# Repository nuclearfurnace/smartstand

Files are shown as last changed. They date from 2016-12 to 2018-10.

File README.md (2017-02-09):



# What is the SmartStand?

The SmartStand is a headphone stand that features not only a built-in, high-quality USB DAC and headphone amplifier, but the ability to detect when your headphones are in use (off the stand) and automatically switch between headphone output and line out, all while presenting as a normal USB audio device to your computer.

# What are the specifications?  How does it sound?

I'm not sure yet!  I haven't reached a rev A for the final design.  Here's the rough breakdown of what the design has:

- XMOS processor for the USB controller ([datasheet](https://www.xmos.com/download/private/XUF208-256-TQ64-Datasheet%281.10%29.pdf), can support UAC2 up to 384kHz at 2 channels)
- TI [PCM5102A](http://www.ti.com/lit/ds/symlink/pcm5102a.pdf) for the DAC
- low-noise power supplies
    - 12V DC wall wart which feeds
        - a TI [TPS563200](http://www.ti.com/lit/ds/symlink/tps563200.pdf) synchronous step-down converter which feeds
            - a TI [TPS7A8300](http://www.ti.com/lit/ds/symlink/tps7a8300.pdf) which provides the 1V0 core supply
        - a TI [TPS563200](http://www.ti.com/lit/ds/symlink/tps563200.pdf) synchronous step-down converter which feeds
            - a TI [TPS7A8300](http://www.ti.com/lit/ds/symlink/tps7a8300.pdf) which provides the digital 3V3 supply
            - a TI [TPS7A8300](http://www.ti.com/lit/ds/symlink/tps7a8300.pdf) which provides the analog 3V3 supply
        - a TI [TPS7A4701](http://www.ti.com/lit/ds/symlink/tps7a47.pdf) which provides the positive 11V0 amplifier rail
        - a TI [TPS7A3301](http://www.ti.com/lit/ds/symlink/tps7a33.pdf) which provides the negative 11V0 amplifier rail
- amplifier section that mirrors the [Objective2](http://nwavguy.blogspot.com/2011/07/o2-headphone-amp.html) headphone amplifier
    - an [NJM2068](http://www.njr.com/semicon/PDF/NJM2068_E.pdf)-based gain stage, with internal switches for dual gain settings
    - an Alps [RK14K](http://www.alps.com/prod/info/E/HTML/Potentiometer/RotaryPotentiometers/RK14K12/RK14K1240A4S.html) volume control pot after the gain stage, big and chunky (1B taper)
    - paralleled [NJM4556A](http://www.njr.com/semicon/PDF/NJM4556A_E.pdf)s for the output stage for lots o' power
- relay-based switching between headphone outputs and line outs, as well as relay-based protection on the headphone outputs to avoid pops and thumps
- Neutrik [NRJ6HH](http://www.neutrik.com/en/audio/plugs-and-jacks/slim-jacks/nrj6hh) 1/4" headphone jack
- Switchcraft [PJRAN2X1U01AUX](http://www.switchcraft.com/Drawings/pjran2x1u__x_series_cd.pdf) RCA outputs
- TE USB type B connector [292304-1](http://www.te.com/usa-en/product-292304-1.html)
- 0.1% precision resistors, and NP0/C0G capacitors in the audio path

# What's in this repository?

This repository will hold all the Eagle CAD design files for the internals, including:

- original, sloppy evaluation boards for the XMOS processor and amplifier section
- the integrated USB DAC/amplifier board (single board that will be used in the unit)
- proximity sensor board (will be located in the stand arm where the headphones rest)
- any schematic- or board-related design files i.e. DRC rules, 3D IDF data, etc

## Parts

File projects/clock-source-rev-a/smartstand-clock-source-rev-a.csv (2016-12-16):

Part | Value | Device | Package | Description | PN
C1 | 100nF | C-EUC0402 | C0402 | CAPACITOR, European symbol | GRM155R71C104KA88D
C2 | 1uF | C-EUC0603 | C0603 | CAPACITOR, European symbol | GRM188R61C105KA93D
J1 | RECE-20279-001E-01 | RECE-20279-001E-01 | IPEX-MHF |  | RECE-20279-001E-01
JP1 |  | PINHD-1X5 | 1X05 | PIN HEADER | 90120-0125
X1 | KC2520K | KC2520K | KC2520C | Clock Oscillators, CMOS, 1.8V/2.5V/3.3V Compatible, 2.5×2.0mm | KC3225K24.5760C1GE00

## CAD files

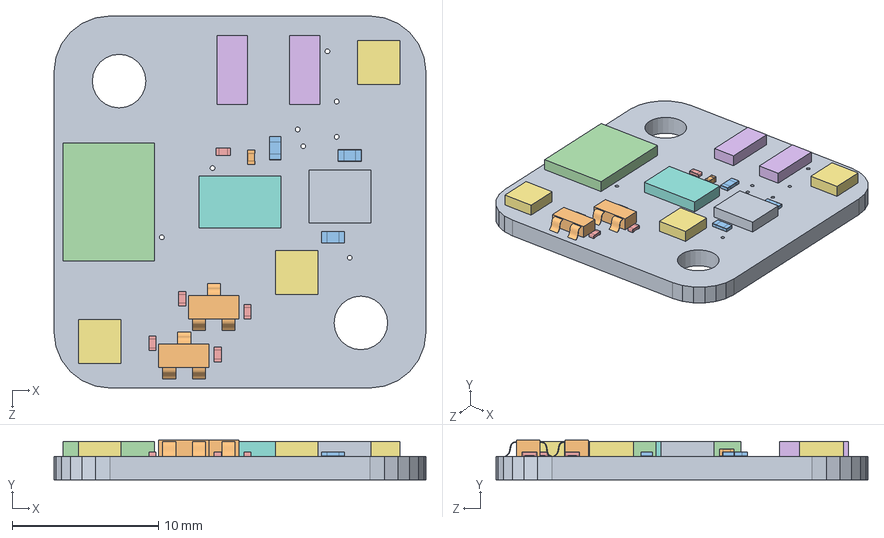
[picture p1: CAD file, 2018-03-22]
enclosure/smartstand-headphone-detection-rev-c.SLDASM
25.4 x 2.70 x 25.4 mm
smartstandheadphonedetectionrevc
C0402
C0603 x 3
T1MSINGLE5POS_T1M5POS
R0402 x 5
TESTPOINT1_5WITHGND_TESTPOINTWITHGND x 2
FIDUCIAL_1MM_FIDUCIAL1MM x 3
VL6180X_VL6180XV0NR
RPDSOG5DBV_LP5907MFX2_8
sot23_4210037 x 2

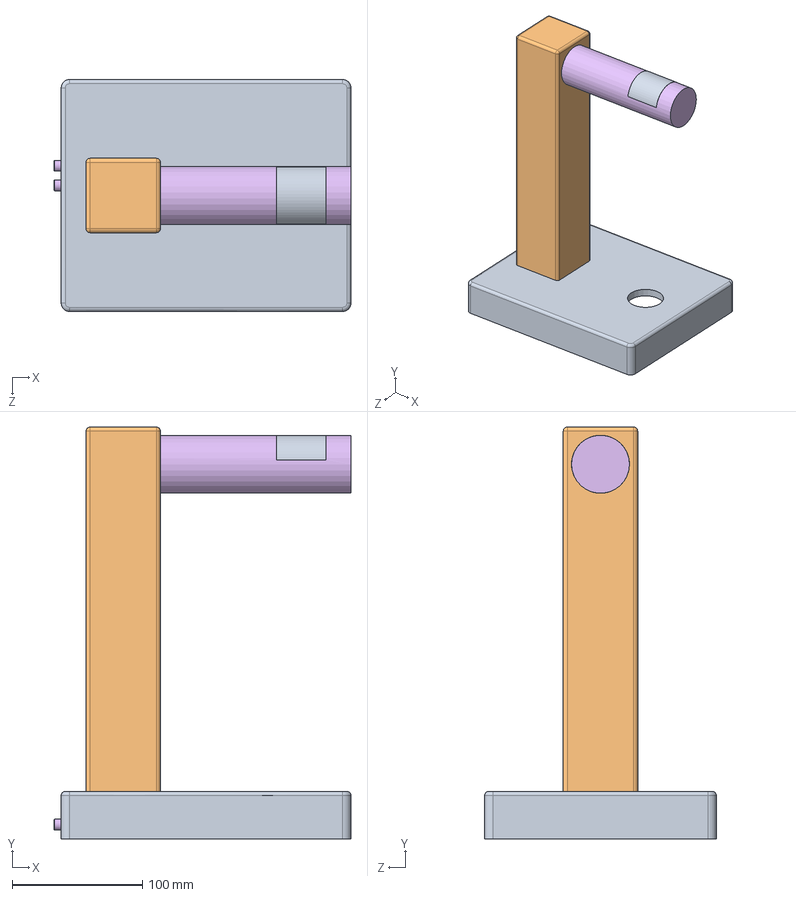
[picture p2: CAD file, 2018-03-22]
enclosure/smartstand-enclosure.SLDASM
227.7 x 315.9 x 177.8 mm
smartstand-enclosure-base
smartstand-enclosure-upright
90016A029_BRASS TAPPING INSERTS FOR HARDWOOD x 4
92240A541_18-8 STAINLESS STEEL HEX HEAD CAP SCREW x 4
91525A118_TYPE 316 STAINLESS STEEL FLAT WASHER x 4
smartstand-enclosure-arm
smartstandheadphonedetectionrevc
C0402 x 75
C0603 x 17
T1MSINGLE5POS_T1M5POS x 2
R0402 x 50
TESTPOINT1_5WITHGND_TESTPOINTWITHGND x 12
FIDUCIAL_1MM_FIDUCIAL1MM x 11
VL6180X_VL6180XV0NR
RPDSOG5DBV_LP5907MFX2_8
sot23_4210037 x 2
smartstand-enclosure-sensor-cover
smartstandusbdacamplifierrevb
CHEMICON_F55_CHEMICON_F55 x 6
C0805 x 22
C1206 x 4
KEMET5MM6_07_2_KEMET5MM6_07_2 x 2
SOD128_5A
SMA_13_6V
DIALIGHT-0603 x 6
2920L_0_6A
PJ002A_PJ002A
NRJ6HH_NRJ6HH
PJRAN2X1U01AUX
N2520-5002
1X07_JP3_1X07
TDKVLP8040_TDKVLP8040 x 2
R1206 x 4
TQ2_TQ212V x 2
TQFP64EXPOSEDPAD_XUF208256TQ64
RPUSONN10_TPD4E02B04DQA
RPDSOG6DBV_TS5A3159DBV x 4
SPVQFNN20_TPS7A3301RGW x 5
RPDSOG20_PCM5102A
SOT457_SZNUD3124
DMP8_NJM4556AM x 3
RPDSOG8DCU_SN74LVC3G34DCU
RPDSOG3_TPD2E007DCK x 2
KC2520C_24_576MHZ x 3
93090A250_PRESS-FIT FEMALE ROUND STANDOFFS x 6
92949A144_18-8 SS BUTTON-HEAD SOCKET CAP SCREW x 6

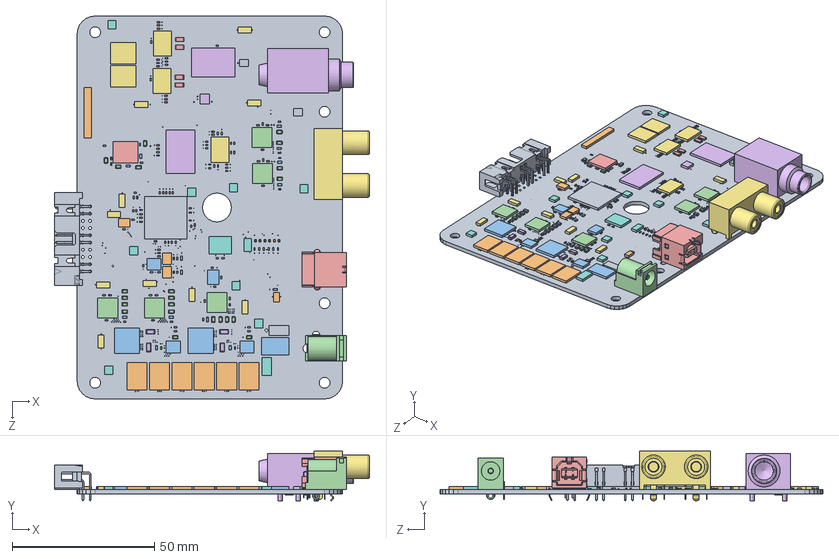
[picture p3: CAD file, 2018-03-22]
enclosure/smartstand-main-board.SLDASM
110.8 x 17.5 x 134.6 mm
smartstandusbdacamplifierrevb
CHEMICON_F55_CHEMICON_F55 x 6
C0603 x 14
C0805 x 22
C0402 x 74
C1206 x 4
KEMET5MM6_07_2_KEMET5MM6_07_2 x 2
SOD128_5A
SMA_13_6V
DIALIGHT-0603 x 6
2920L_0_6A
PJ002A_PJ002A
NRJ6HH_NRJ6HH
PJRAN2X1U01AUX
T1MSINGLE5POS_T1M5POS
N2520-5002
1X07_JP3_1X07
TDKVLP8040_TDKVLP8040 x 2
R0402 x 45
R1206 x 4
TQ2_TQ212V x 2
TESTPOINT1_5WITHGND_TESTPOINTWITHGND x 10
FIDUCIAL_1MM_FIDUCIAL1MM x 8
TQFP64EXPOSEDPAD_XUF208256TQ64
RPUSONN10_TPD4E02B04DQA
RPDSOG6DBV_TS5A3159DBV x 4
SPVQFNN20_TPS7A3301RGW x 5
RPDSOG20_PCM5102A
SOT457_SZNUD3124
DMP8_NJM4556AM x 3
RPDSOG8DCU_SN74LVC3G34DCU
RPDSOG3_TPD2E007DCK x 2
KC2520C_24_576MHZ x 3

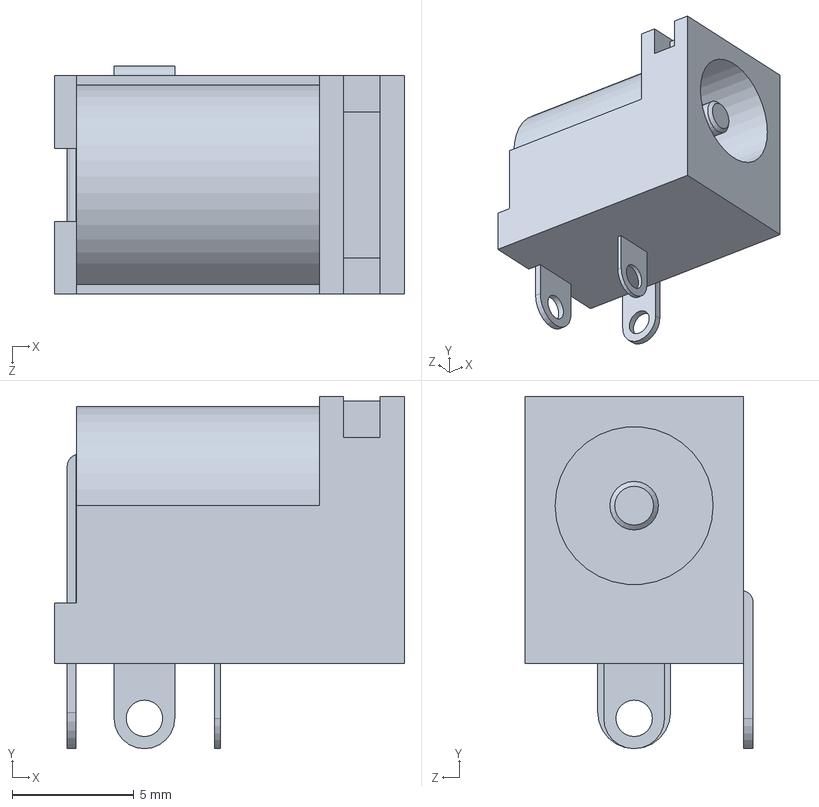
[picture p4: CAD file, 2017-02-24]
enclosure/component-library/pj-002a.SLDPRT
14.4 x 14.5 x 9.40 mm

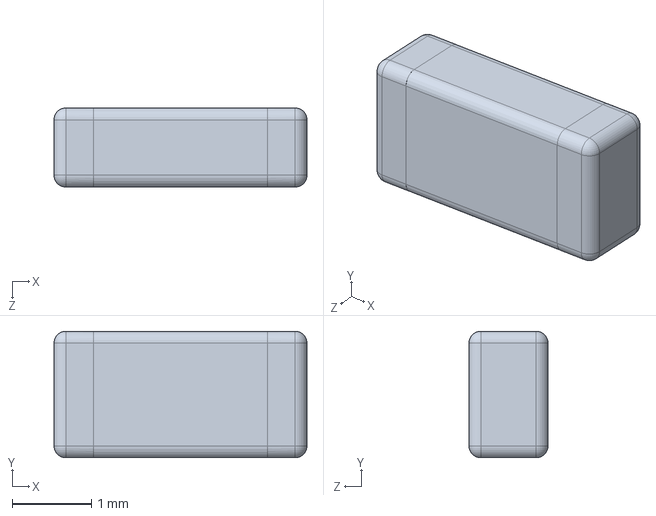
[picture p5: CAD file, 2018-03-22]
enclosure/C1206.SLDPRT
3.20 x 1.60 x 1 mm

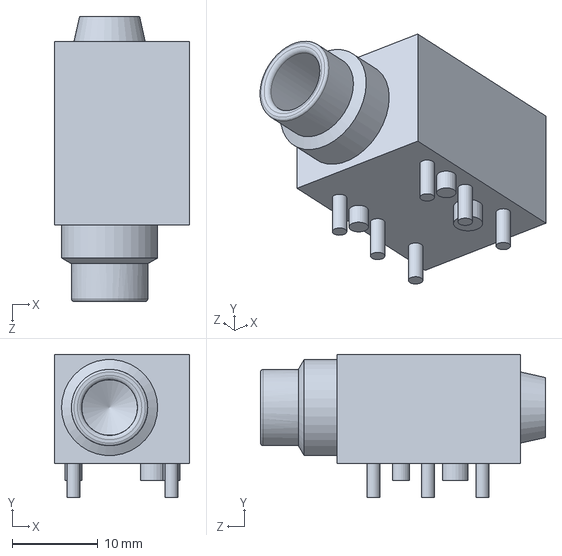
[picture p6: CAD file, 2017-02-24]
enclosure/component-library/NRJ6HH.SLDPRT
15.8 x 16.7 x 33.2 mm

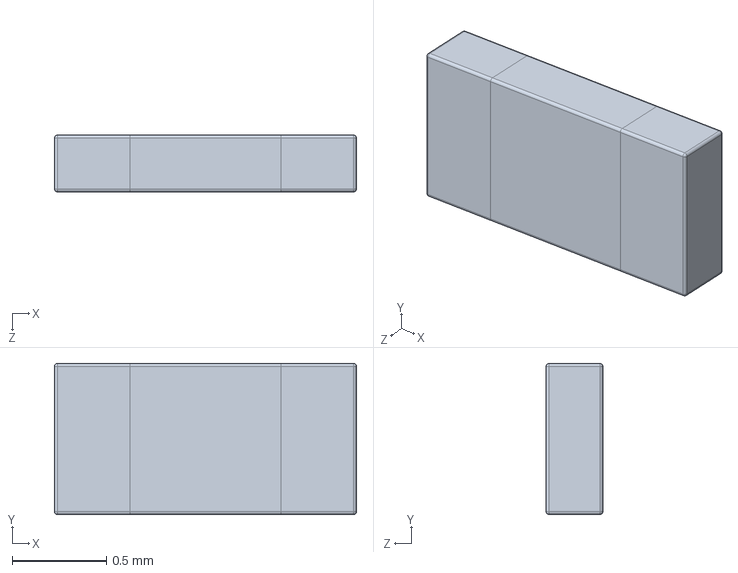
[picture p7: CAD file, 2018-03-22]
enclosure/C0603.SLDPRT
1.60 x 0.8 x 0.3 mm

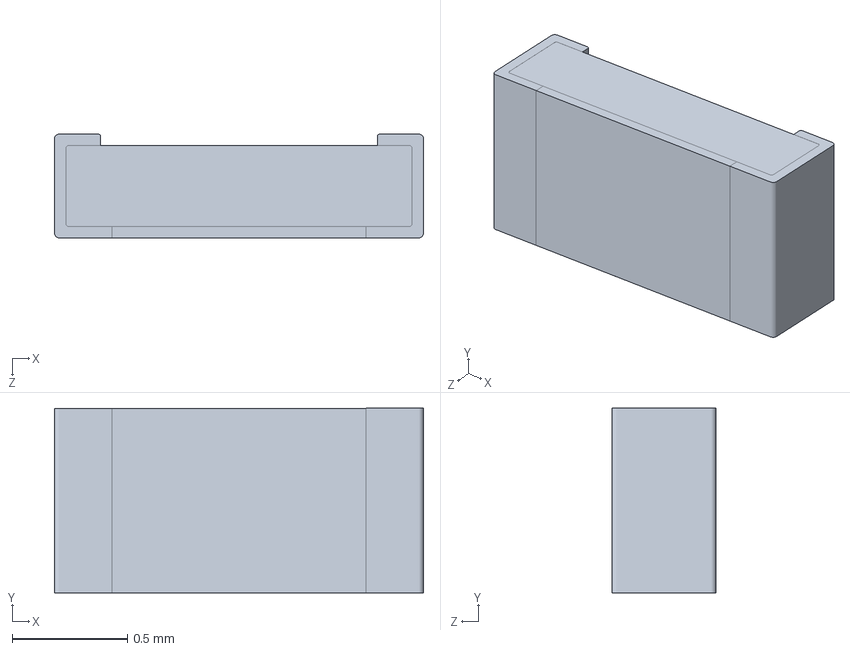
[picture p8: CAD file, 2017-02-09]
enclosure/component-library/R0603.SLDPRT
1.60 x 0.8 x 0.45 mm

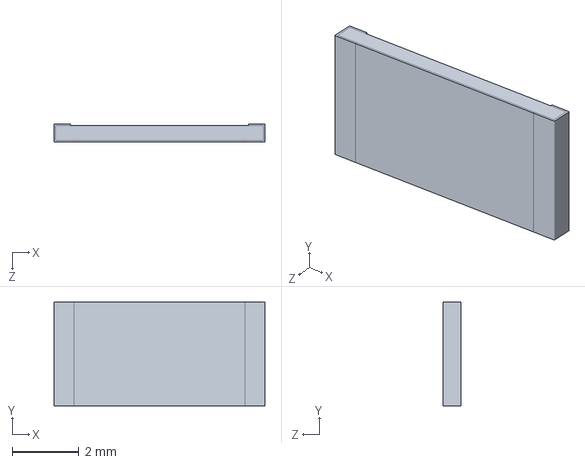
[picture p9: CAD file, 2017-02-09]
enclosure/component-library/R2512.SLDPRT
6.30 x 3.10 x 0.55 mm

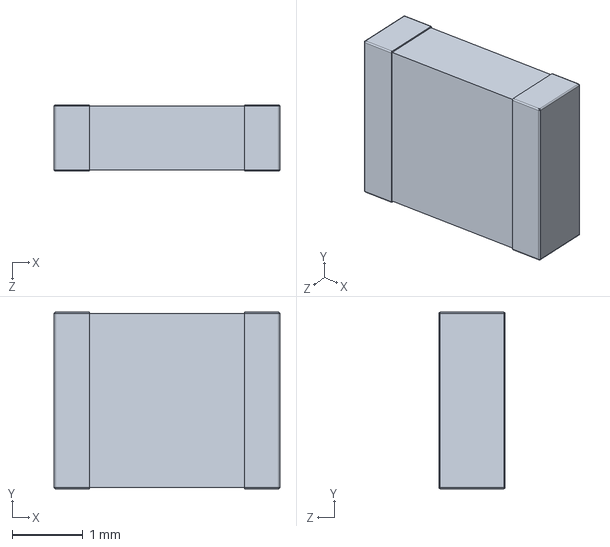
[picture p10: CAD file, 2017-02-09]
enclosure/component-library/C1210.SLDPRT
3.20 x 2.50 x 0.94 mm

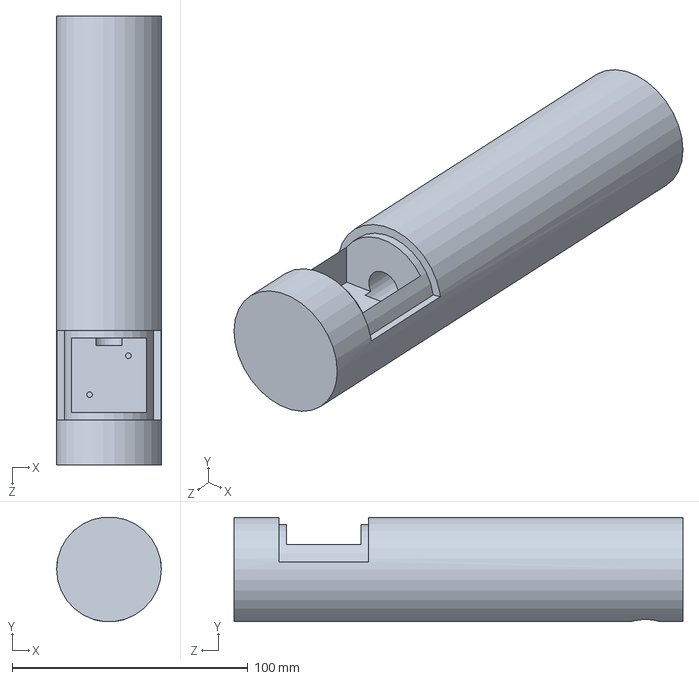
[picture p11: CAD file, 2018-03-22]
enclosure/smartstand-enclosure-arm.SLDPRT
44.5 x 44.3 x 190.5 mm

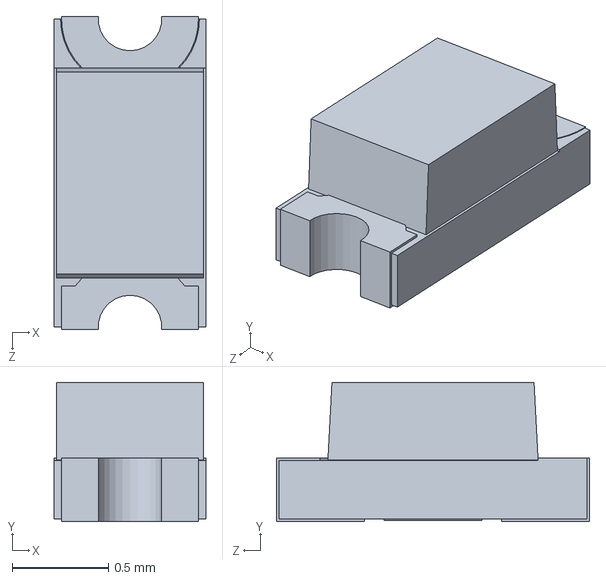
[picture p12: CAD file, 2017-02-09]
enclosure/component-library/DIALIGHT-0603.SLDPRT
0.787 x 0.724 x 1.63 mm

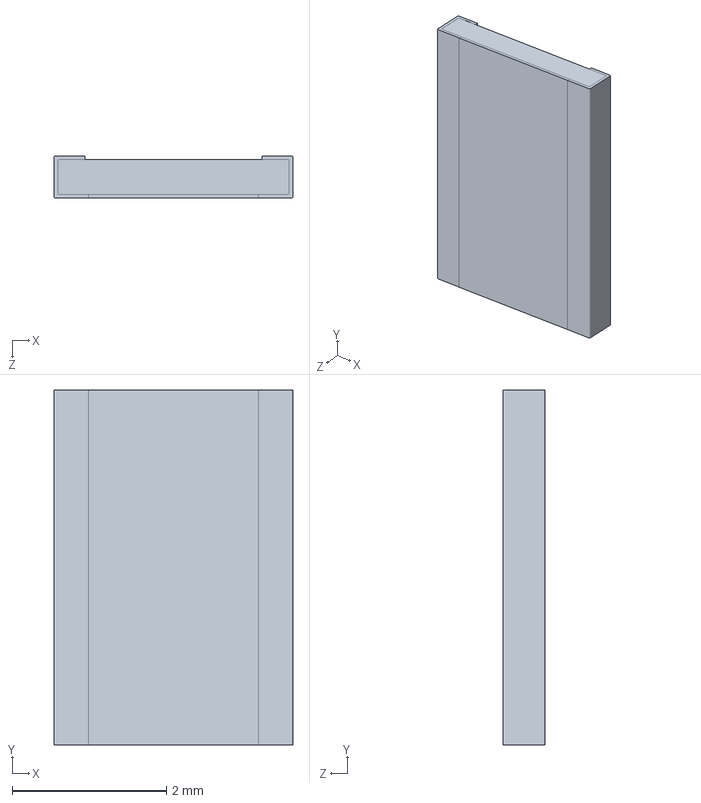
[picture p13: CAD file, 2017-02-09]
enclosure/component-library/R1218.SLDPRT
3.10 x 4.61 x 0.55 mm

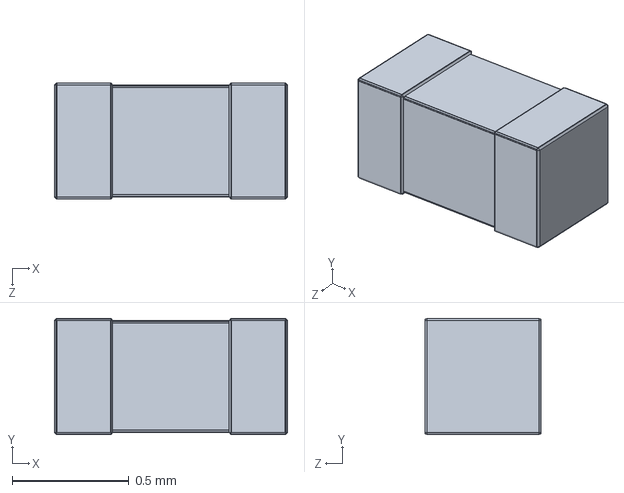
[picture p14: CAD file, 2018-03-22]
enclosure/C0402.SLDPRT
1.00 x 0.5 x 0.5 mm

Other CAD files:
enclosure/DIALIGHT-0603.SLDPRT
enclosure/component-library/C0603.SLDPRT
enclosure/component-library/C0805.SLDPRT
enclosure/component-library/R0402.SLDPRT
enclosure/2920L_0_6A.sldprt
enclosure/90016A029_BRASS TAPPING INSERTS FOR HARDWOOD.SLDPRT
enclosure/91375A730_ALLOY STEEL CUP POINT SET SCREW.SLDPRT
enclosure/91525A118_TYPE 316 STAINLESS STEEL FLAT WASHER.SLDPRT
enclosure/92240A538_18-8 STAINLESS STEEL HEX HEAD CAP SCREW.SLDPRT
enclosure/92240A541_18-8 STAINLESS STEEL HEX HEAD CAP SCREW.SLDPRT
enclosure/92525A198_THREAD-FORMING SCREW FOR SHEET METAL IRON.SLDPRT
enclosure/92949A144_18-8 SS BUTTON-HEAD SOCKET CAP SCREW.SLDPRT
enclosure/93090A250_PRESS-FIT FEMALE ROUND STANDOFFS.SLDPRT
enclosure/93195A223_THREAD-FORMING SCREW FOR SHEET METAL IRON.SLDPRT
enclosure/961206-6404-AR.SLDPRT
enclosure/C0805.SLDPRT
enclosure/CHEMICON_F55_CHEMICON_F55.sldprt
enclosure/DMP8_NJM4556AM.sldprt
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

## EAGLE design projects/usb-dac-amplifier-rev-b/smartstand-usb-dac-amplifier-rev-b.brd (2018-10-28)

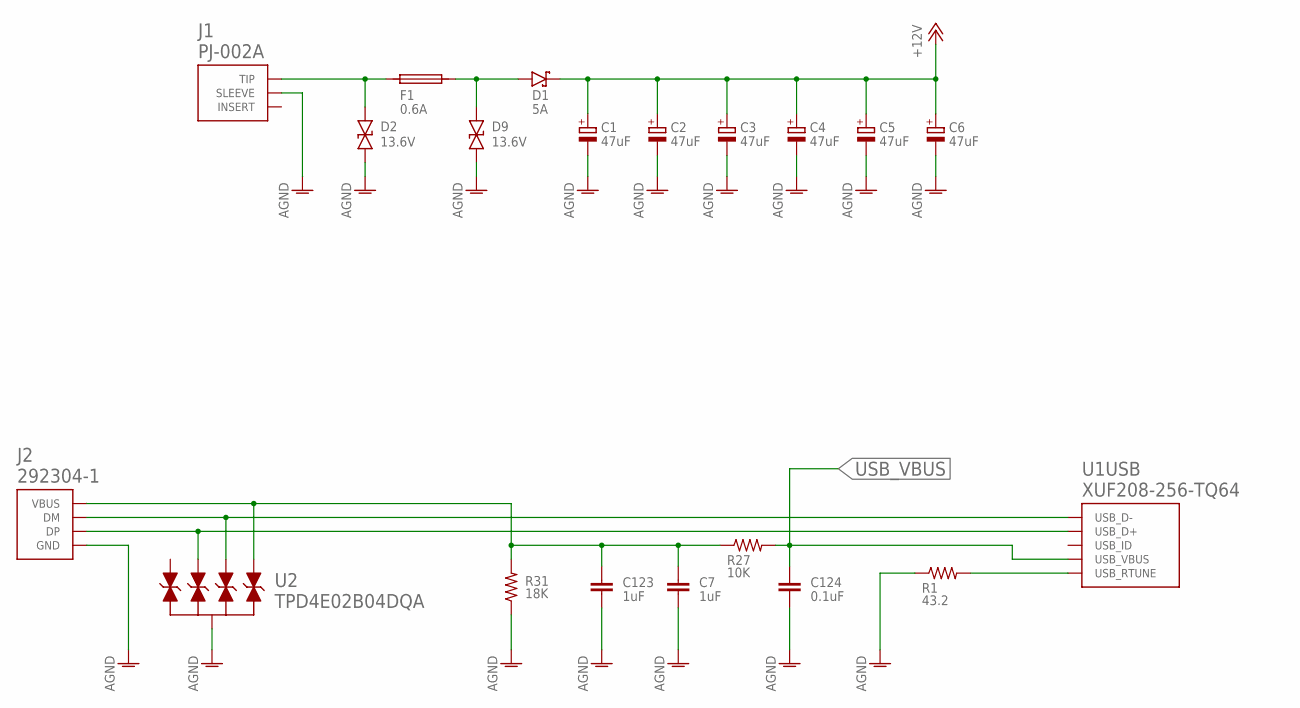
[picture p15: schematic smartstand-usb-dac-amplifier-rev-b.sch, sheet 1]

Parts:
C1, C2, C3, C4, C5, C6: 47uF; CHEMICON_F55
C7, C123: 1uF; C0603
C124: 0.1uF; C0402
D1: 5A; SOD128; MPN PMEG3050BEP,115
D2, D9: 13.6V; SMA; MPN P4SMA16CA
F1: 0.6A; 2920L; MPN 2920L030DR
J1: PJ-002A; VOLTAGE 12.0; MPN PJ-002A
J2: 292304-1; 292304; MPN 292304-1
R1: 43.2; R0402; MPN RK73B1ETTP430J
R27: 10K; R0402
R31: 18K; R0402
U1: XUF208-256-TQ64; TQFP-64-EXPOSED-PAD
U2: TPD4E02B04DQA; R-PUSON-N10; MPN TPD4E02B04DQAR

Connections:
+12V: C1.+, C2.+, C3.+, C4.+, C5.+, C6.+, D1.C; also elsewhere on the board
AGND: C1.-, C2.-, C3.-, C4.-, C5.-, C6.-, C7.2, C123.2, C124.2, D2.A, D9.A, J1.2 (SLEEVE), J2.P$4 (GND), R1.1, R31.1, U2.P$3 (GND), U2.P$8 (GND); also elsewhere on the board
unnamed: D2.C, F1.P$1 (1), J1.1 (TIP)
unnamed: D1.A, D9.C, F1.P$2 (2)
unnamed: R1.2, U1.P$24 (USB_RTUNE)
unnamed: C7.1, C123.1, J2.P$1 (VBUS), R27.1, R31.2, U2.P$5 (IO4), U2.P$6 (IO4)
USB_D_N: J2.P$2 (DM), U1.P$26 (USB_D-), U2.P$4 (IO3), U2.P$7 (IO3)
USB_D_P: J2.P$3 (DP), U1.P$25 (USB_D+), U2.P$2 (IO2), U2.P$9 (IO2)
USB_VBUS: C124.1, R27.2, U1.P$23 (USB_VBUS); also elsewhere on the board

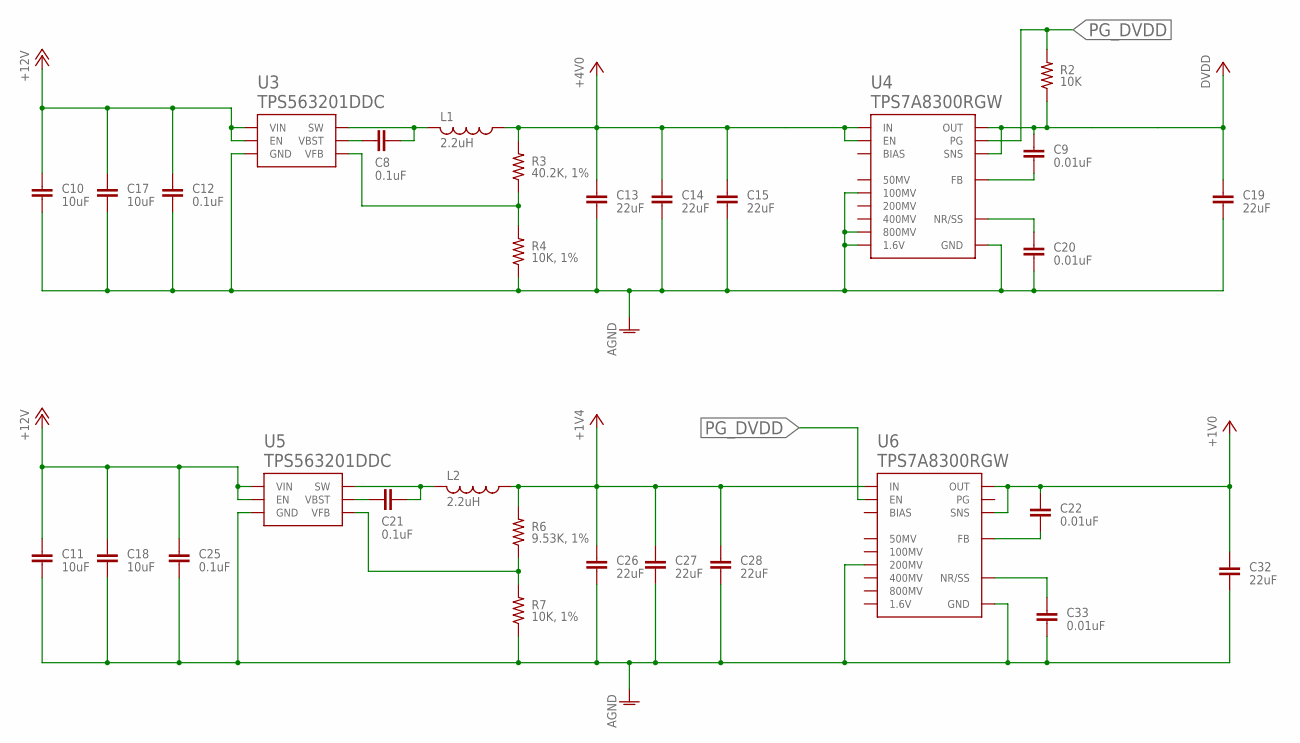
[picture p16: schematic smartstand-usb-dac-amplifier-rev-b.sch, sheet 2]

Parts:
C8, C21: 0.1uF; C0603; MPN GCM188R71H104KA57J
C9, C20, C22, C33: 0.01uF; C0402
C10, C11, C17, C18: 10uF; C0603; MPN GRM188R6YA106MA73D
C12, C25: 0.1uF; C0402
C13, C14, C15, C19, C26, C27, C28, C32: 22uF; C0603; MPN ZRB18AR61A226ME01L
L1, L2: 2.2uH; TDK-VLP8040; MPN VLP8040T-2R2N
R2: 10K; R0402; MPN RC0402FR-0710KL
R3: 40.2K, 1%; R0402; MPN RK73H1ETTP4022F
R4, R7: 10K, 1%; R0402; MPN RC0402FR-0710KL
R6: 9.53K, 1%; R0402; MPN RC0402FR-079K53L
U3, U5: TPS563201DDC; R-PDSO-G6-DBV; MPN TPS563201DDC
U4, U6: TPS7A8300RGW; S-PVQFN-N20; MPN TPS7A8300RGWR

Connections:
+1V0: C22.1, C32.1, U6.P$1 (OUT), U6.P$2 (SNS), U6.P$19 (OUT), U6.P$20 (OUT); also elsewhere on the board
+1V4: C26.1, C27.1, C28.1, L2.P$1 (1), R6.2, U6.P$15 (IN), U6.P$16 (IN), U6.P$17 (IN); also elsewhere on the board
+4V0: C13.1, C14.1, C15.1, L1.P$1 (1), R3.2, U4.P$14 (EN), U4.P$15 (IN), U4.P$16 (IN), U4.P$17 (IN); also elsewhere on the board
+12V: C10.1, C11.1, C12.1, C17.1, C18.1, C25.1, U3.3 (VIN), U3.5 (EN), U5.3 (VIN), U5.5 (EN); also elsewhere on the board
AGND: C10.2, C11.2, C12.2, C13.2, C14.2, C15.2, C17.2, C18.2, C19.2, C20.2, C25.2, C26.2, C27.2, C28.2, C32.2, C33.2, R4.1, R7.1, U3.1 (GND), U4.P$6 (100MV), U4.P$8 (GND), U4.P$10 (800MV), U4.P$11 (1.6V), U4.P$18 (GND), U4.P$21 (GND), U4.P$22 (GND), U4.P$23 (GND), U4.P$24 (GND), U4.P$25 (GND), U4.P$26 (GND), U4.P$27 (GND), U4.P$28 (GND), U4.P$29 (GND), U4.P$EP (GND), U5.1 (GND), U6.P$7 (200MV), U6.P$8 (GND), U6.P$18 (GND), U6.P$21 (GND), U6.P$22 (GND), U6.P$23 (GND), U6.P$24 (GND), U6.P$25 (GND), U6.P$26 (GND), U6.P$27 (GND), U6.P$28 (GND), U6.P$29 (GND), U6.P$EP (GND); also elsewhere on the board
DVDD: C9.1, C19.1, R2.1, U4.P$1 (OUT), U4.P$2 (SNS), U4.P$19 (OUT), U4.P$20 (OUT); also elsewhere on the board
unnamed: C20.1, U4.P$13 (NR/SS)
unnamed: C9.2, U4.P$3 (FB)
unnamed: C8.2, L1.P$2 (2), U3.2 (SW)
unnamed: C8.1, U3.6 (VBST)
unnamed: R3.1, R4.2, U3.4 (VFB)
unnamed: C21.2, L2.P$2 (2), U5.2 (SW)
unnamed: C21.1, U5.6 (VBST)
unnamed: R6.1, R7.2, U5.4 (VFB)
unnamed: C33.1, U6.P$13 (NR/SS)
unnamed: C22.2, U6.P$3 (FB)
PG_DVDD: R2.2, U4.P$4 (PG), U6.P$14 (EN)

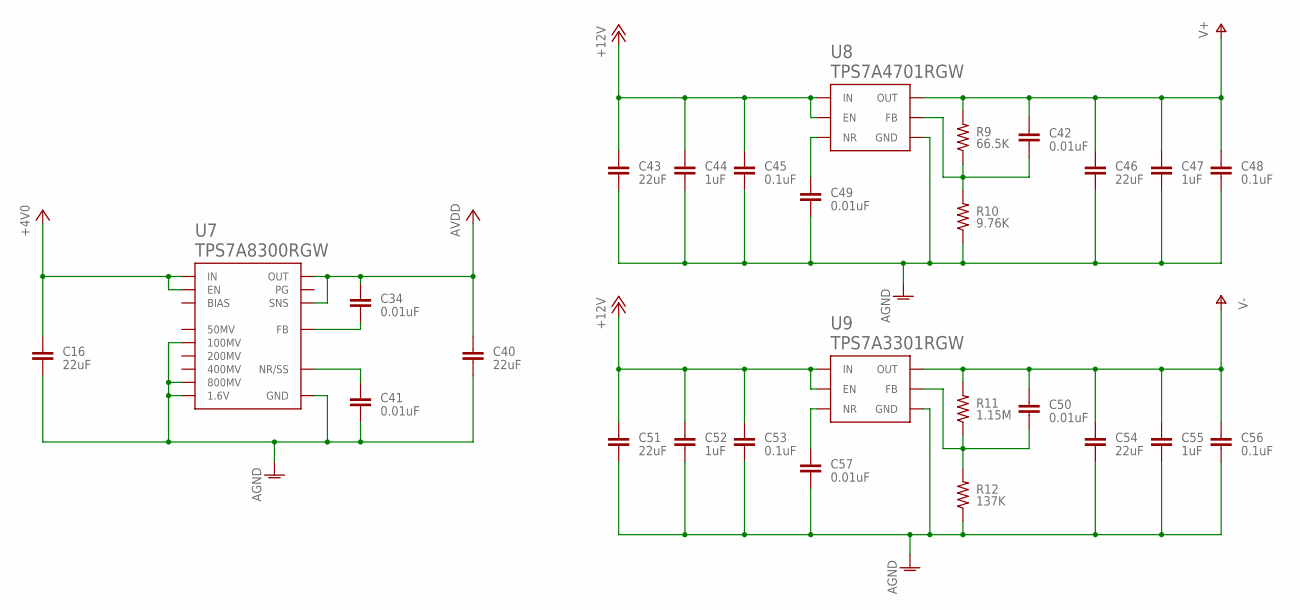
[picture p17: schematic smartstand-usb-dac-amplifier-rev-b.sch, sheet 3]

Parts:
C16, C40: 22uF; C0603; MPN ZRB18AR61A226ME01L
C34, C41, C42, C49, C50, C57: 0.01uF; C0402
C43, C46, C51, C54: 22uF; C0603; MPN GRM188R6YA106MA73D
C44, C47, C52, C55: 1uF; C0603
C45, C48, C53, C56: 0.1uF; C0402
R9: 66.5K; R0402; MPN RK73H1ETTP6652F
R10: 9.76K; R0402; MPN RC0402FR-079K76L
R11: 1.15M; R0402; MPN RK73H1ETTP1154F
R12: 137K; R0402; MPN RC0402FR-07137KL
U7: TPS7A8300RGW; S-PVQFN-N20; MPN TPS7A8300RGWR
U8: TPS7A4701RGW; S-PVQFN-N20; MPN TPS7A4701RGWR
U9: TPS7A3301RGW; S-PVQFN-N20; MPN TPS7A3301RGWR

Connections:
+4V0: C16.1, U7.P$14 (EN), U7.P$15 (IN), U7.P$16 (IN), U7.P$17 (IN); also elsewhere on the board
+12V: C43.1, C44.1, C45.1, C51.1, C52.1, C53.1, U8.P$13 (EN), U8.P$15 (IN), U8.P$16 (IN), U9.P$13 (EN), U9.P$15 (IN), U9.P$16 (IN); also elsewhere on the board
AGND: C16.2, C40.2, C41.2, C43.2, C44.2, C45.2, C46.2, C47.2, C48.2, C49.2, C51.2, C52.2, C53.2, C54.2, C55.2, C56.2, C57.2, R10.1, R12.1, U7.P$6 (100MV), U7.P$8 (GND), U7.P$10 (800MV), U7.P$11 (1.6V), U7.P$18 (GND), U7.P$21 (GND), U7.P$22 (GND), U7.P$23 (GND), U7.P$24 (GND), U7.P$25 (GND), U7.P$26 (GND), U7.P$27 (GND), U7.P$28 (GND), U7.P$29 (GND), U7.P$EP (GND), U8.P$7 (GND), U8.P$17 (GND), U8.P$18 (GND), U8.P$19 (GND), U8.P$21 (GND), U8.P$22 (GND), U8.P$23 (GND), U8.P$24 (GND), U8.P$25 (GND), U8.P$26 (GND), U8.P$27 (GND), U8.P$28 (GND), U8.P$29 (GND), U8.P$EP (GND), U9.P$7 (GND), U9.P$17 (GND), U9.P$18 (GND), U9.P$19 (GND), U9.P$21 (GND), U9.P$22 (GND), U9.P$23 (GND), U9.P$24 (GND), U9.P$25 (GND), U9.P$26 (GND), U9.P$27 (GND), U9.P$28 (GND), U9.P$29 (GND), U9.P$EP (GND); also elsewhere on the board
AVDD: C34.1, C40.1, U7.P$1 (OUT), U7.P$2 (SNS), U7.P$19 (OUT), U7.P$20 (OUT); also elsewhere on the board
unnamed: C57.1, U9.P$14 (NR)
unnamed: C49.1, U8.P$14 (NR)
unnamed: C42.2, R9.1, R10.2, U8.P$3 (FB)
unnamed: C50.2, R11.1, R12.2, U9.P$3 (FB)
unnamed: C41.1, U7.P$13 (NR/SS)
unnamed: C34.2, U7.P$3 (FB)
V+: C42.1, C46.1, C47.1, C48.1, R9.2, U8.P$1 (OUT), U8.P$20 (OUT); also elsewhere on the board
V-: C50.1, C54.1, C55.1, C56.1, R11.2, U9.P$1 (OUT), U9.P$20 (OUT); also elsewhere on the board

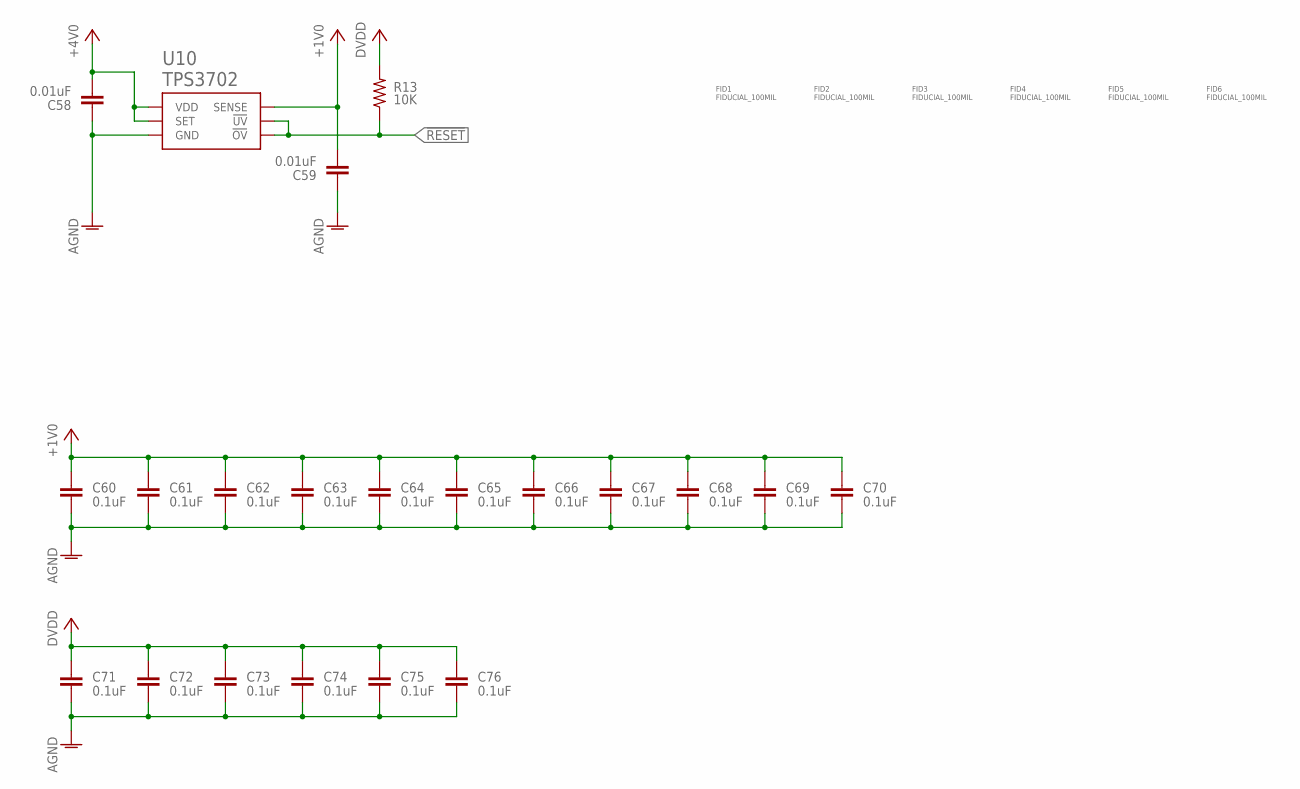
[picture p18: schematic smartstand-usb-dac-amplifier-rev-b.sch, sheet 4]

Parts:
C58, C59: 0.01uF; C0402
C60, C61, C62, C63, C64, C65, C66, C67, C68, C69, C70, C71, C72, C73, C74, C75, C76: 0.1uF; C0402
FID1, FID2, FID3, FID4, FID5, FID6: FIDUCIAL_100MIL
R13: 10K; R0402
U10: TPS3702; R-PDSO-G6-DBV; MPN TPS3702CX10DDCT

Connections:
!RESET: R13.1, U10.1 (!UV), U10.6 (!OV); also elsewhere on the board
+1V0: C59.2, C60.1, C61.1, C62.1, C63.1, C64.1, C65.1, C66.1, C67.1, C68.1, C69.1, C70.1, U10.3 (SENSE); also elsewhere on the board
+4V0: C58.2, U10.4 (SET), U10.5 (VDD); also elsewhere on the board
AGND: C58.1, C59.1, C60.2, C61.2, C62.2, C63.2, C64.2, C65.2, C66.2, C67.2, C68.2, C69.2, C70.2, C71.2, C72.2, C73.2, C74.2, C75.2, C76.2, U10.2 (GND); also elsewhere on the board
DVDD: C71.1, C72.1, C73.1, C74.1, C75.1, C76.1, R13.2; also elsewhere on the board

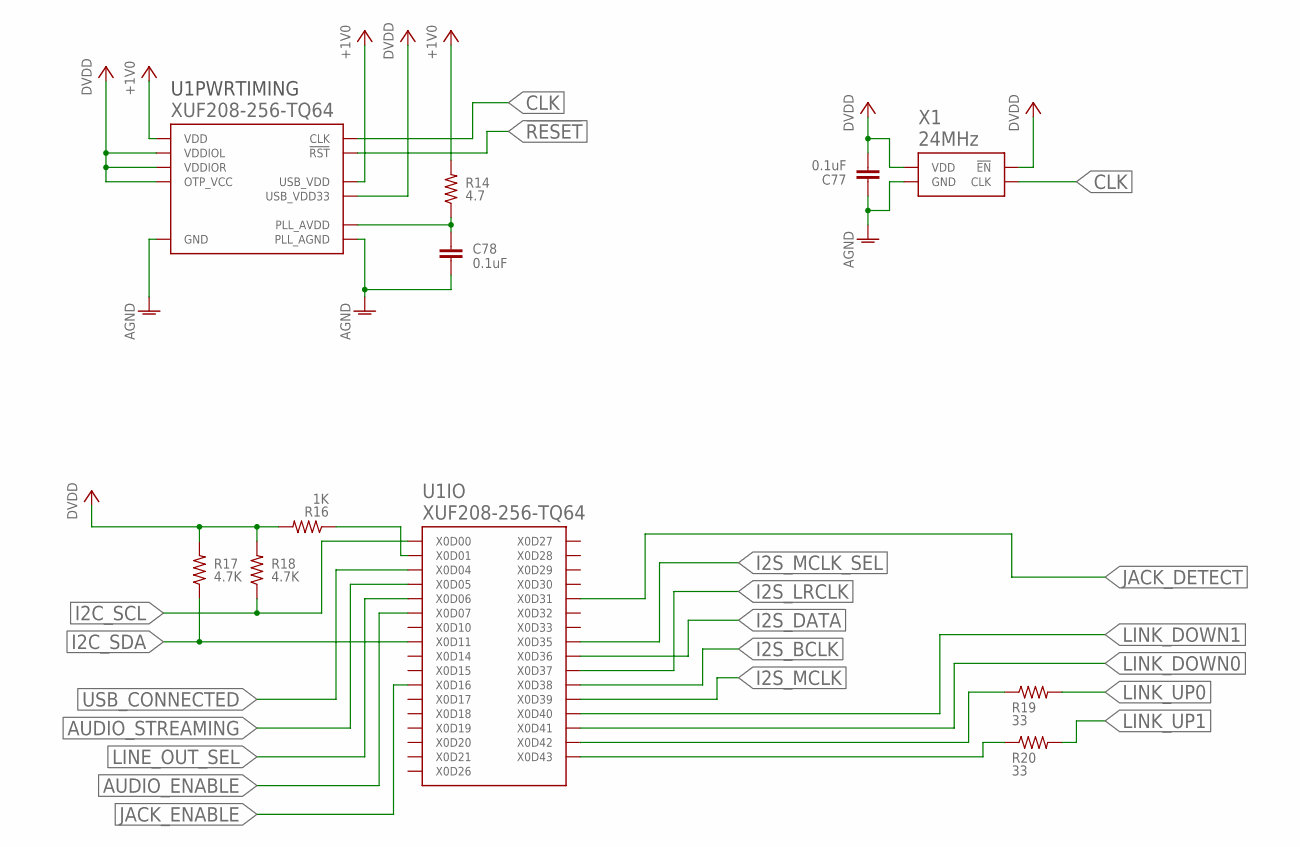
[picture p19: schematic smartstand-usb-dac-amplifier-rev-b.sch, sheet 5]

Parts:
C77, C78: 0.1uF; C0402
R14: 4.7; R0402; MPN RCS04024R70JNED
R16: 1K; R0402
R17, R18: 4.7K; R0402
R19, R20: 33; R0402; MPN RK73B1ETTP330J
U1: XUF208-256-TQ64; TQFP-64-EXPOSED-PAD
X1: 24MHz; KC2520C; MPN KC2520C24.0000C2LE00

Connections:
!RESET: U1.P$57 (!RST); also elsewhere on the board
+1V0: R14.2, U1.P$9 (VDD), U1.P$10 (VDD), U1.P$20 (VDD), U1.P$27 (USB_VDD), U1.P$31 (VDD), U1.P$39 (VDD), U1.P$40 (VDD), U1.P$41 (VDD), U1.P$52 (VDD), U1.P$56 (VDD), U1.P$59 (VDD); also elsewhere on the board
AGND: C77.1, C78.2, U1.P$54 (PLL_AGND), U1.P$65 (GND), U1.P$66 (GND), U1.P$67 (GND), U1.P$68 (GND), U1.P$69 (GND), U1.P$70 (GND), U1.P$71 (GND), U1.P$72 (GND), U1.P$73 (GND), U1.P$74 (GND), X1.P$2 (GND); also elsewhere on the board
AUDIO_ENABLE: U1.P$19 (X0D07); also elsewhere on the board
AUDIO_STREAMING: U1.P$17 (X0D05); also elsewhere on the board
CLK: U1.P$58 (CLK), X1.P$3 (CLK); also elsewhere on the board
DVDD: C77.2, R16.2, R17.2, R18.2, U1.P$3 (VDDIOL), U1.P$13 (VDDIOL), U1.P$22 (USB_VDD33), U1.P$34 (VDDIOR), U1.P$44 (VDDIOR), U1.P$55 (OTP_VCC), X1.P$1 (!EN), X1.P$4 (VDD); also elsewhere on the board
I2C_SCL: R18.1, U1.P$14 (X0D00); also elsewhere on the board
I2C_SDA: R17.1, U1.P$16 (X0D11); also elsewhere on the board
I2S_BCLK: U1.P$2 (X0D38); also elsewhere on the board
I2S_DATA: U1.P$1 (X0D36); also elsewhere on the board
I2S_LRCLK: U1.P$64 (X0D37); also elsewhere on the board
I2S_MCLK: U1.P$4 (X0D39); also elsewhere on the board
I2S_MCLK_SEL: U1.P$42 (X0D35); also elsewhere on the board
JACK_DETECT: U1.P$51 (X0D31); also elsewhere on the board
JACK_ENABLE: U1.P$35 (X0D16); also elsewhere on the board
LINE_OUT_SEL: U1.P$18 (X0D06); also elsewhere on the board
LINK_DOWN0: U1.P$6 (X0D41); also elsewhere on the board
LINK_DOWN1: U1.P$5 (X0D40); also elsewhere on the board
LINK_UP0: R19.2; also elsewhere on the board
LINK_UP1: R20.2; also elsewhere on the board
unnamed: R19.1, U1.P$7 (X0D42)
unnamed: R20.1, U1.P$8 (X0D43)
unnamed: R16.1, U1.P$11 (X0D01)
PLL_AVDD: C78.1, R14.1, U1.P$53 (PLL_AVDD); also elsewhere on the board
USB_CONNECTED: U1.P$15 (X0D04); also elsewhere on the board

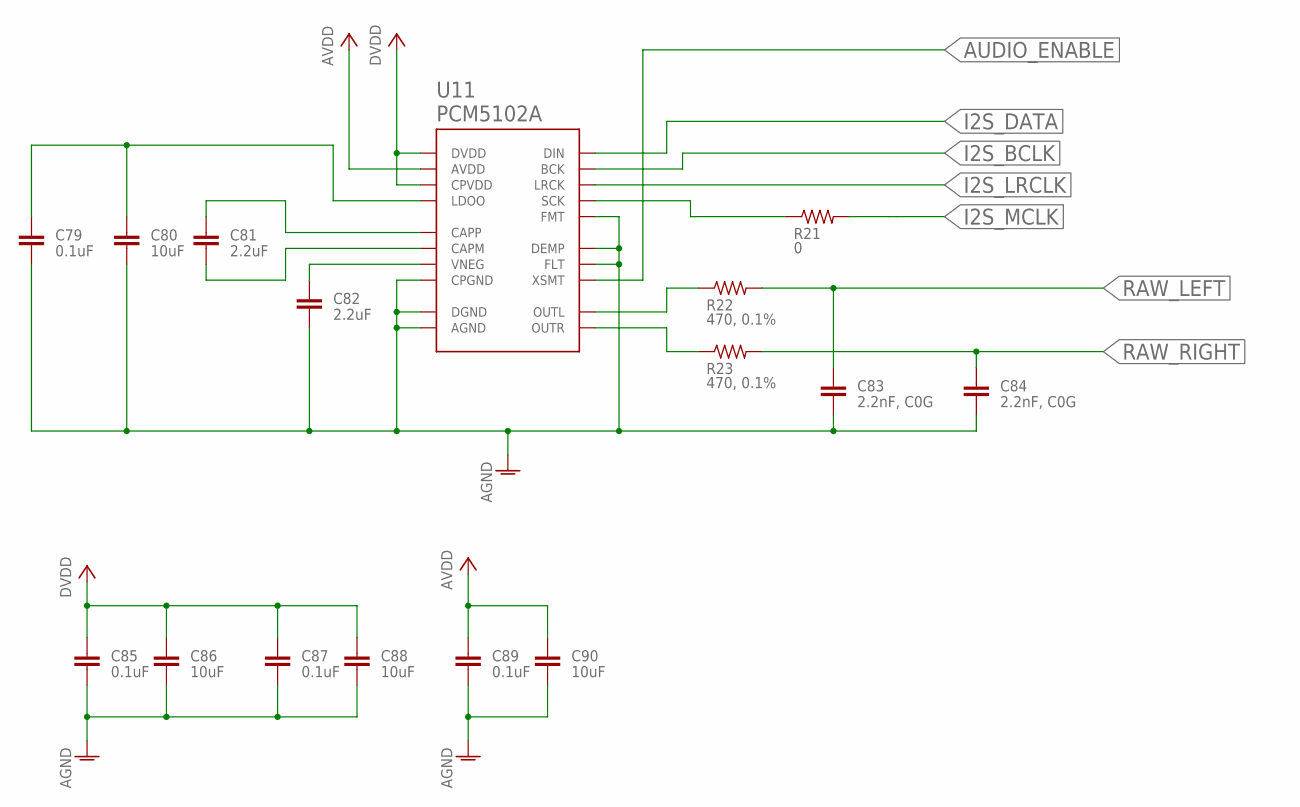
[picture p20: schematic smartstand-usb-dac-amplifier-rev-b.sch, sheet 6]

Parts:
C79, C85, C87, C89: 0.1uF; C0402
C80, C86, C88, C90: 10uF; C0805; MPN GRM21BR61E106KA73L
C81, C82: 2.2uF; C0603; MPN GRM188R61C225KE15D
C83, C84: 2.2nF, C0G; C0402; MPN C0402C222J3GACTU
R21: 0; R0402
R22, R23: 470, 0.1%; R0402; MPN RG1005P-471-B-T5
U11: PCM5102A; R-PDSO-G20; MPN PCM5102APWR

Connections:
AGND: C79.2, C80.2, C82.2, C83.2, C84.2, C85.2, C86.2, C87.2, C88.2, C89.2, C90.2, U11.P$3 (CPGND), U11.P$9 (AGND), U11.P$10 (DEMP), U11.P$11 (FLT), U11.P$16 (FMT), U11.P$19 (DGND); also elsewhere on the board
AUDIO_ENABLE: U11.P$17 (XSMT); also elsewhere on the board
AVDD: C89.1, C90.1, U11.P$8 (AVDD); also elsewhere on the board
DVDD: C85.1, C86.1, C87.1, C88.1, U11.P$1 (CPVDD), U11.P$20 (DVDD); also elsewhere on the board
I2S_BCLK: U11.P$13 (BCK); also elsewhere on the board
I2S_DATA: U11.P$14 (DIN); also elsewhere on the board
I2S_LRCLK: U11.P$15 (LRCK); also elsewhere on the board
I2S_MCLK: R21.2; also elsewhere on the board
unnamed: C81.1, U11.P$2 (CAPP)
unnamed: C81.2, U11.P$4 (CAPM)
unnamed: C82.1, U11.P$5 (VNEG)
unnamed: C79.1, C80.1, U11.P$18 (LDOO)
unnamed: R22.1, U11.P$6 (OUTL)
unnamed: R23.1, U11.P$7 (OUTR)
unnamed: R21.1, U11.P$12 (SCK)
RAW_LEFT: C83.1, R22.2; also elsewhere on the board
RAW_RIGHT: C84.1, R23.2; also elsewhere on the board

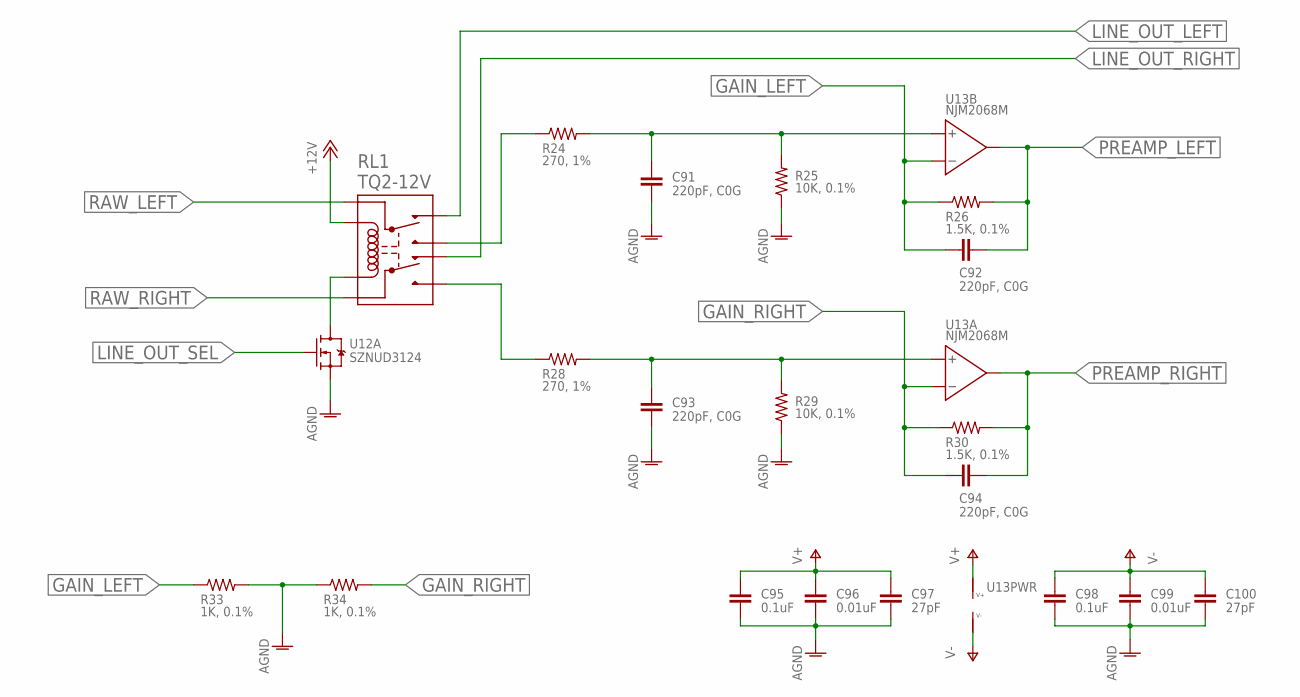
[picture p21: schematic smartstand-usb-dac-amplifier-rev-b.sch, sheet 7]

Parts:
C91, C92, C93, C94: 220pF, C0G; C0402; MPN GRM1555C1H221JA01J
C95, C98: 0.1uF; C0402
C96, C99: 0.01uF; C0402
C97, C100: 27pF; C0402
R24, R28: 270, 1%; R0603; MPN MCT06030C2700FP500
R25, R29: 10K, 0.1%; R0603; MPN MCT06030C1002FP500
R26, R30: 1.5K, 0.1%; R0603; MPN MCT06030C1501FP500
R33, R34: 1K, 0.1%; R0603; MPN MCT06030C1001FP500
RL1: TQ2-12V; TQ2; MPN TQ2-12V
U12: SZNUD3124; SOT-457; MPN SZNUD3124DMT1G
U13: NJM2068M; DMP8; MPN NJM2068M-TE1

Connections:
+12V: RL1.P$1 (COIL_P); also elsewhere on the board
AGND: C91.2, C93.2, C95.2, C96.2, C97.2, C98.2, C99.2, C100.2, R25.1, R29.1, R33.2, R34.1, U12.1 (S); also elsewhere on the board
GAIN_LEFT: C92.1, R26.1, R33.1, U13.P$6 (-IN)
GAIN_RIGHT: C94.1, R30.1, R34.2, U13.P$2 (-IN)
LINE_OUT_LEFT: RL1.P$2 (NC1); also elsewhere on the board
LINE_OUT_RIGHT: RL1.P$9 (NC2); also elsewhere on the board
LINE_OUT_SEL: U12.2 (G); also elsewhere on the board
unnamed: RL1.P$10 (COIL_N), U12.6 (D)
unnamed: C93.1, R28.2, R29.2, U13.P$3 (+IN)
unnamed: C91.1, R24.2, R25.2, U13.P$5 (+IN)
unnamed: R28.1, RL1.P$7 (NO2)
unnamed: R24.1, RL1.P$4 (NO1)
PREAMP_LEFT: C92.2, R26.2, U13.P$7 (OUT); also elsewhere on the board
PREAMP_RIGHT: C94.2, R30.2, U13.P$1 (OUT); also elsewhere on the board
RAW_LEFT: RL1.P$3 (COM1); also elsewhere on the board
RAW_RIGHT: RL1.P$8 (COM2); also elsewhere on the board
V+: C95.1, C96.1, C97.1, U13.P$8 (V+); also elsewhere on the board
V-: C98.1, C99.1, C100.1, U13.P$4 (V-); also elsewhere on the board

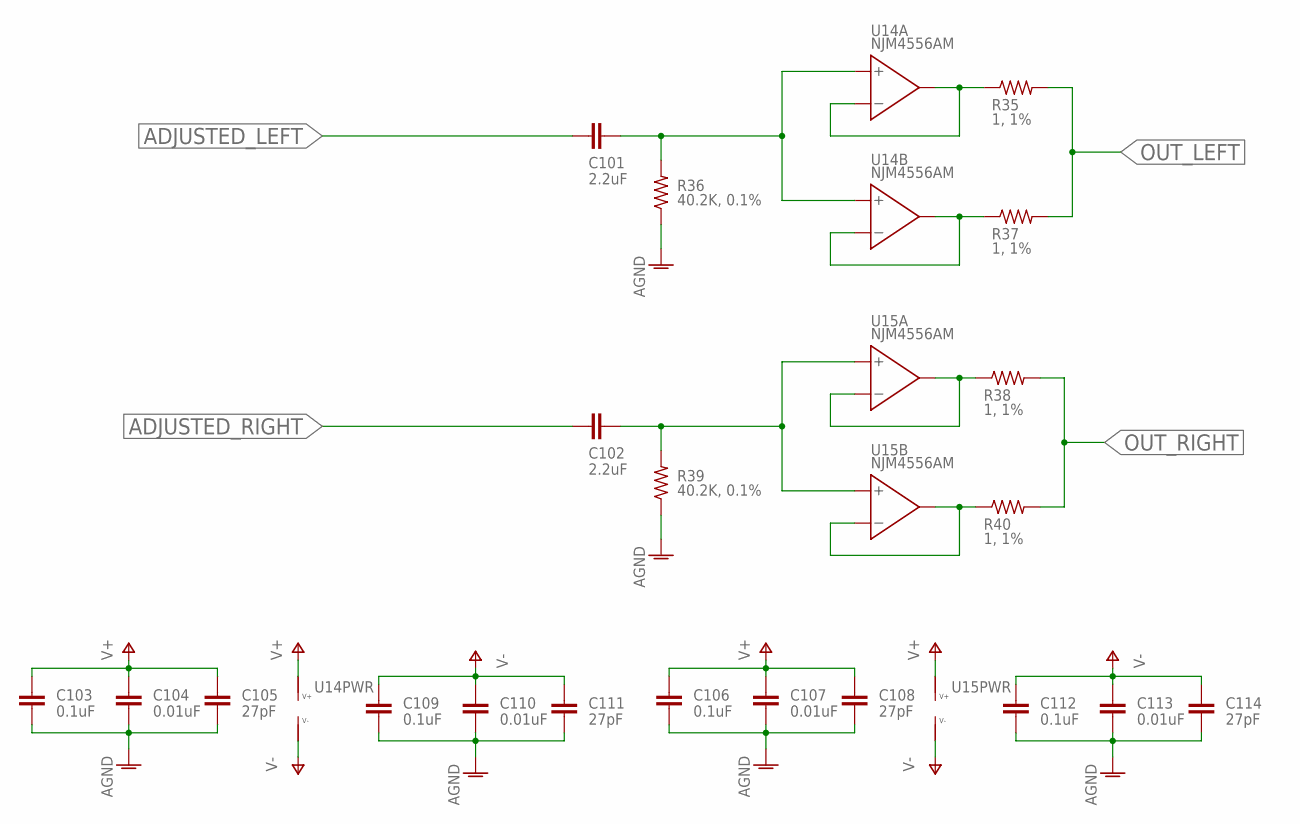
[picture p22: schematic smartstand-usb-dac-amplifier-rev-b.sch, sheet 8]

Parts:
C101, C102: 2.2uF; KEMET-5MM-6.0-7.2; MPN RSBCC4220Z310K
C103, C106, C109, C112: 0.1uF; C0402
C104, C107, C110, C113: 0.01uF; C0402
C105, C108, C111, C114: 27pF; C0402
R35, R37, R38, R40: 1, 1%; R1206; MPN MCA12060C1008FP500
R36, R39: 40.2K, 0.1%; R0402; MPN RG1005P-4022-B-T5
U14, U15: NJM4556AM; DMP8; MPN NJM4556AM-TE1

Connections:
ADJUSTED_LEFT: C101.P$1 (1); also elsewhere on the board
ADJUSTED_RIGHT: C102.P$1 (1); also elsewhere on the board
AGND: C103.2, C104.2, C105.2, C106.2, C107.2, C108.2, C109.2, C110.2, C111.2, C112.2, C113.2, C114.2, R36.1, R39.1; also elsewhere on the board
unnamed: C101.P$2 (2), R36.2, U14.P$3 (+IN), U14.P$5 (+IN)
unnamed: C102.P$2 (2), R39.2, U15.P$3 (+IN), U15.P$5 (+IN)
unnamed: R35.1, U14.P$1 (OUT), U14.P$2 (-IN)
unnamed: R37.1, U14.P$6 (-IN), U14.P$7 (OUT)
unnamed: R38.1, U15.P$1 (OUT), U15.P$2 (-IN)
unnamed: R40.1, U15.P$6 (-IN), U15.P$7 (OUT)
OUT_LEFT: R35.2, R37.2; also elsewhere on the board
OUT_RIGHT: R38.2, R40.2; also elsewhere on the board
V+: C103.1, C104.1, C105.1, C106.1, C107.1, C108.1, U14.P$8 (V+), U15.P$8 (V+); also elsewhere on the board
V-: C109.1, C110.1, C111.1, C112.1, C113.1, C114.1, U14.P$4 (V-), U15.P$4 (V-); also elsewhere on the board

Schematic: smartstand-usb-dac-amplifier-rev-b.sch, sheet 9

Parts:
C115, C118: 1uF; C0603
C116, C119, C121: 0.1uF; C0402
C117, C120: 0.01uF; C0402
R41, R42: 0; R0402
R43: 100K; R0402
U16: TS5A3159DBV; R-PDSO-G6-DBV; MPN TS5A3159DBVR
X2: 22.5792MHz; KC2520C; MPN KC2520K22.5792C1GE00
X3: 24.576MHz; KC2520C; MPN KC2520K24.5760C1GE00

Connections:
AGND: C115.2, C116.2, C117.2, C118.2, C119.2, C120.2, C121.2, R43.1, U16.2 (GND), X2.P$2 (GND), X3.P$2 (GND); also elsewhere on the board
DVDD: C115.1, C116.1, C117.1, C118.1, C119.1, C120.1, C121.1, U16.5 (V+), X2.P$1 (!EN), X2.P$4 (VDD), X3.P$1 (!EN), X3.P$4 (VDD); also elsewhere on the board
I2S_MCLK: U16.4 (COM); also elsewhere on the board
I2S_MCLK_48: R42.2, X3.P$3 (CLK)
I2S_MCLK_441: R41.2, X2.P$3 (CLK)
I2S_MCLK_SEL: R43.2, U16.6 (IN); also elsewhere on the board
unnamed: R41.1, U16.1 (NO)
unnamed: R42.1, U16.3 (NC)

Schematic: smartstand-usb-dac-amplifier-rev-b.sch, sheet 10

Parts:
C122: 0.1uF; C0402
J3: NRJ6HH; MPN NRJ6HH
J4: PJRAN2X1U01AUX; PJRAN2X1U; MPN PJRAN2X1U01AUX
R45: 100K; R0402
R46: 10K; R0402
R47: 49.9K; R0402; MPN RC0402FR-0749K9L
RL2: TQ2-12V; TQ2; MPN TQ2-12V
U12: SZNUD3124; SOT-457; MPN SZNUD3124DMT1G
U18, U19: TPD2E007DCK; R-PDSO-G3; MPN TPD2E007DCKR

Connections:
+12V: RL2.P$1 (COIL_P); also elsewhere on the board
AGND: C122.2, J3.S (SLEEVE), J4.L_SLEEVE (SLEEVE), J4.R_SLEEVE (SLEEVE), R46.1, RL2.P$2 (NC1), RL2.P$9 (NC2), U12.4 (S), U18.3 (GND), U19.3 (GND); also elsewhere on the board
DVDD: R45.2; also elsewhere on the board
JACK_DETECT: C122.1, R47.2; also elsewhere on the board
JACK_ENABLE: U12.5 (G); also elsewhere on the board
LINE_OUT_LEFT: J4.L_TIP (TIP), U19.2 (IO2); also elsewhere on the board
LINE_OUT_RIGHT: J4.R_TIP (TIP), U19.1 (IO1); also elsewhere on the board
unnamed: J3.T (TIP), R46.2, RL2.P$3 (COM1), U18.2 (IO2)
unnamed: J3.R (RING), RL2.P$8 (COM2), U18.1 (IO1)
unnamed: RL2.P$10 (COIL_N), U12.3 (D)
unnamed: J3.TN (T_SENSE), R45.1, R47.1
OUT_LEFT: RL2.P$4 (NO1); also elsewhere on the board
OUT_RIGHT: RL2.P$7 (NO2); also elsewhere on the board

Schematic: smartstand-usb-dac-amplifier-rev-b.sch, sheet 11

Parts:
D3, D4, D5, D6, D7, D8: 1.8V, 10mA; DIALIGHT-0603; MPN 598-8070-107F
R48: 330; R0402
R49, R50, R51, R52, R53: 220; R0402
U17: SN74LVC3G34DCU; R-PDSO-G8-DCU; MPN SN74LVC3G34DCUT

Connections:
AGND: R48.1, R49.1, R50.1, R51.1, R52.1, R53.1, U17.4 (GND); also elsewhere on the board
AUDIO_STREAMING: U17.3 (A); also elsewhere on the board
AVDD: D8.1 (A); also elsewhere on the board
DVDD: D5.1 (A), U17.8 (VDD); also elsewhere on the board
LINE_OUT_SEL: U17.6 (A); also elsewhere on the board
unnamed: D8.2 (C), R53.2
unnamed: D3.2 (C), R48.2
unnamed: D5.2 (C), R50.2
unnamed: D4.1 (A), U17.7 (Y)
unnamed: D4.2 (C), R49.2
unnamed: D6.1 (A), U17.5 (Y)
unnamed: D6.2 (C), R51.2
unnamed: D7.1 (A), U17.2 (Y)
unnamed: D7.2 (C), R52.2
USB_CONNECTED: U17.1 (A); also elsewhere on the board
USB_VBUS: D3.1 (A); also elsewhere on the board

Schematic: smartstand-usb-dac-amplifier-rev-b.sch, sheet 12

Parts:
J5: T1M-5POS; T1M-SINGLE-5POS; MPN T1M-05-T-S-RA-TR
JP1: PINHD-1X10; 1X10
JP2: PINHD-2X10; 2X10; MPN N2520-5002RB
TP1, TP2, TP3, TP4, TP5, TP6, TP7, TP8, TP9, TP10: TESTPOINT-WITH-GND; TESTPOINT-1.5-WITH-GND
U1: XUF208-256-TQ64; TQFP-64-EXPOSED-PAD

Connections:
!RESET: JP2.15; also elsewhere on the board
+1V0: TP8.S; also elsewhere on the board
+1V4: TP7.S; also elsewhere on the board
+4V0: TP3.S; also elsewhere on the board
+12V: JP1.1, TP2.S; also elsewhere on the board
ADJUSTED_LEFT: JP1.6; also elsewhere on the board
ADJUSTED_RIGHT: JP1.5; also elsewhere on the board
AGND: J5.1, J5.5, JP1.2, JP1.7, JP2.4, JP2.8, JP2.12, JP2.16, JP2.20, TP1.G, TP2.G, TP3.G, TP4.G, TP5.G, TP6.G, TP7.G, TP8.G, TP9.G, TP10.G; also elsewhere on the board
AVDD: TP5.S; also elsewhere on the board
CLK: TP1.S; also elsewhere on the board
DVDD: J5.2, JP1.8, TP6.S; also elsewhere on the board
I2C_SCL: J5.4, JP1.10; also elsewhere on the board
I2C_SDA: J5.3, JP1.9; also elsewhere on the board
LINK_DOWN0: JP2.14; also elsewhere on the board
LINK_DOWN1: JP2.18; also elsewhere on the board
LINK_UP0: JP2.10; also elsewhere on the board
LINK_UP1: JP2.6; also elsewhere on the board
unnamed: JP2.7, U1.P$60 (TMS)
unnamed: JP2.9, U1.P$61 (TCK)
unnamed: JP2.5, U1.P$62 (TDI)
unnamed: JP2.13, U1.P$63 (TDO)
PLL_AVDD: TP4.S; also elsewhere on the board
PREAMP_LEFT: JP1.3; also elsewhere on the board
PREAMP_RIGHT: JP1.4; also elsewhere on the board
V+: TP9.S; also elsewhere on the board
V-: TP10.S; also elsewhere on the board

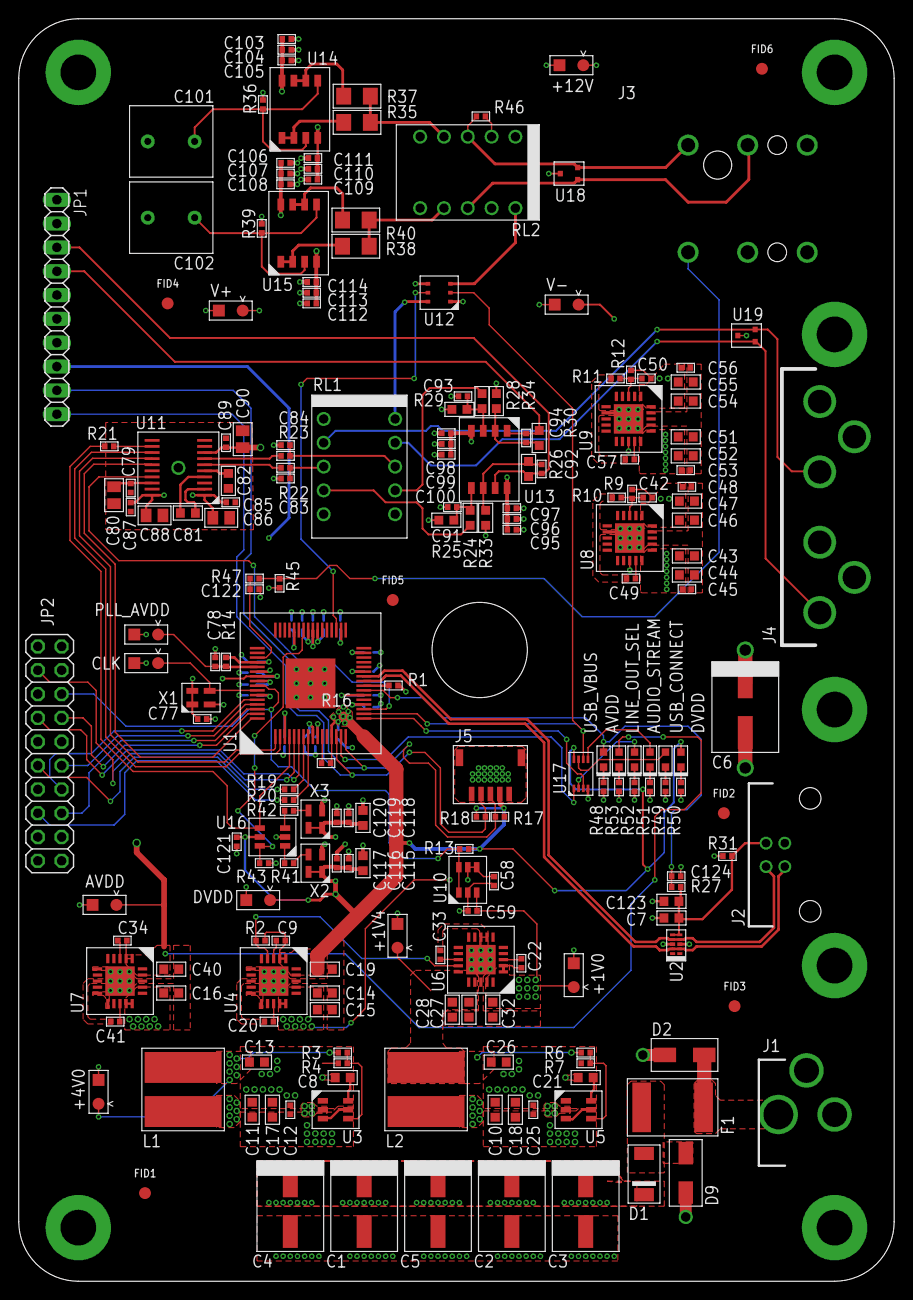
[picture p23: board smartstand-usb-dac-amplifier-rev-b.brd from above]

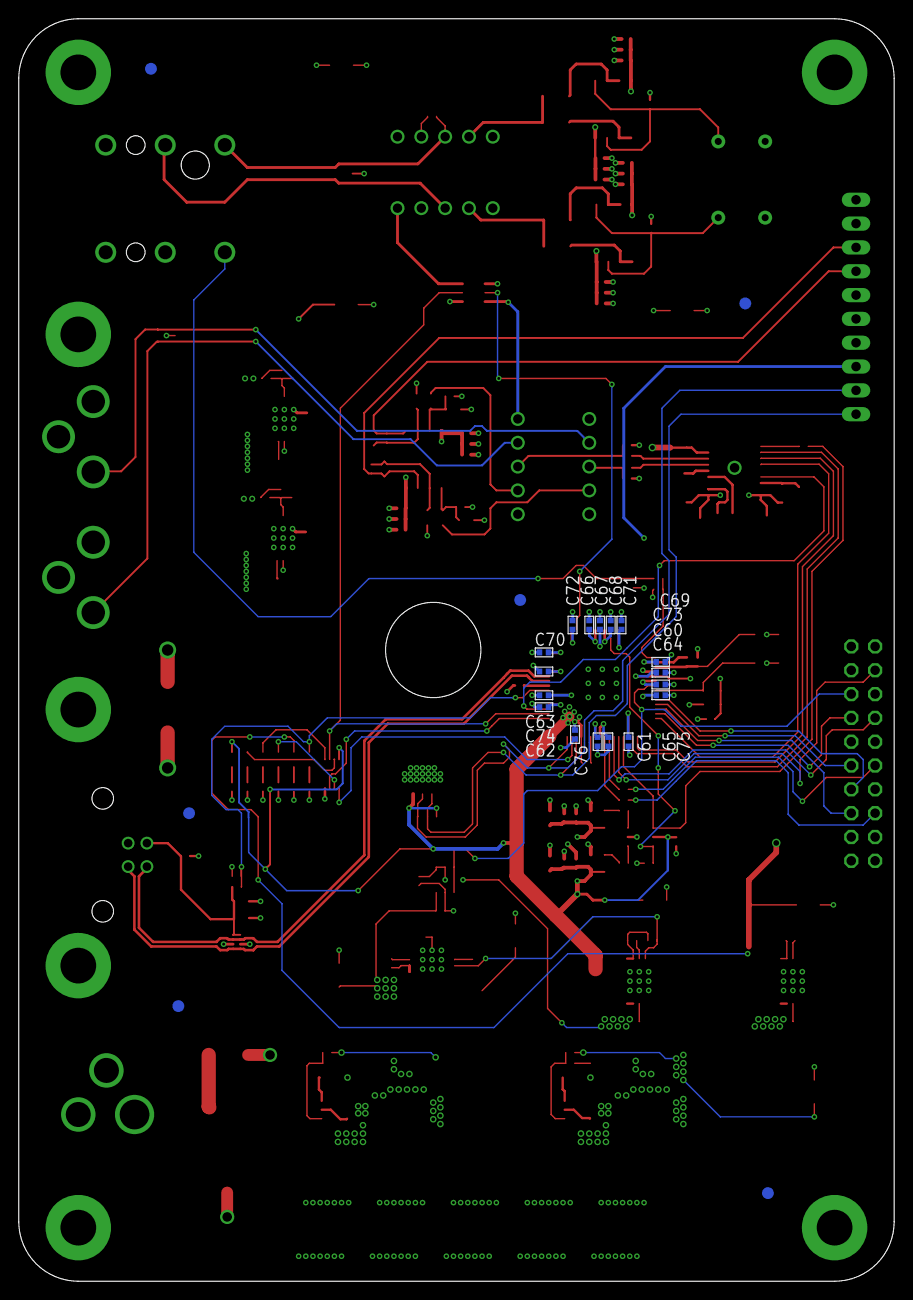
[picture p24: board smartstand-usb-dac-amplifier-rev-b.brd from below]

Board: 4 copper layers, 93.3 x 134.6 mm, 221 parts (17 on the bottom side), 107 nets.

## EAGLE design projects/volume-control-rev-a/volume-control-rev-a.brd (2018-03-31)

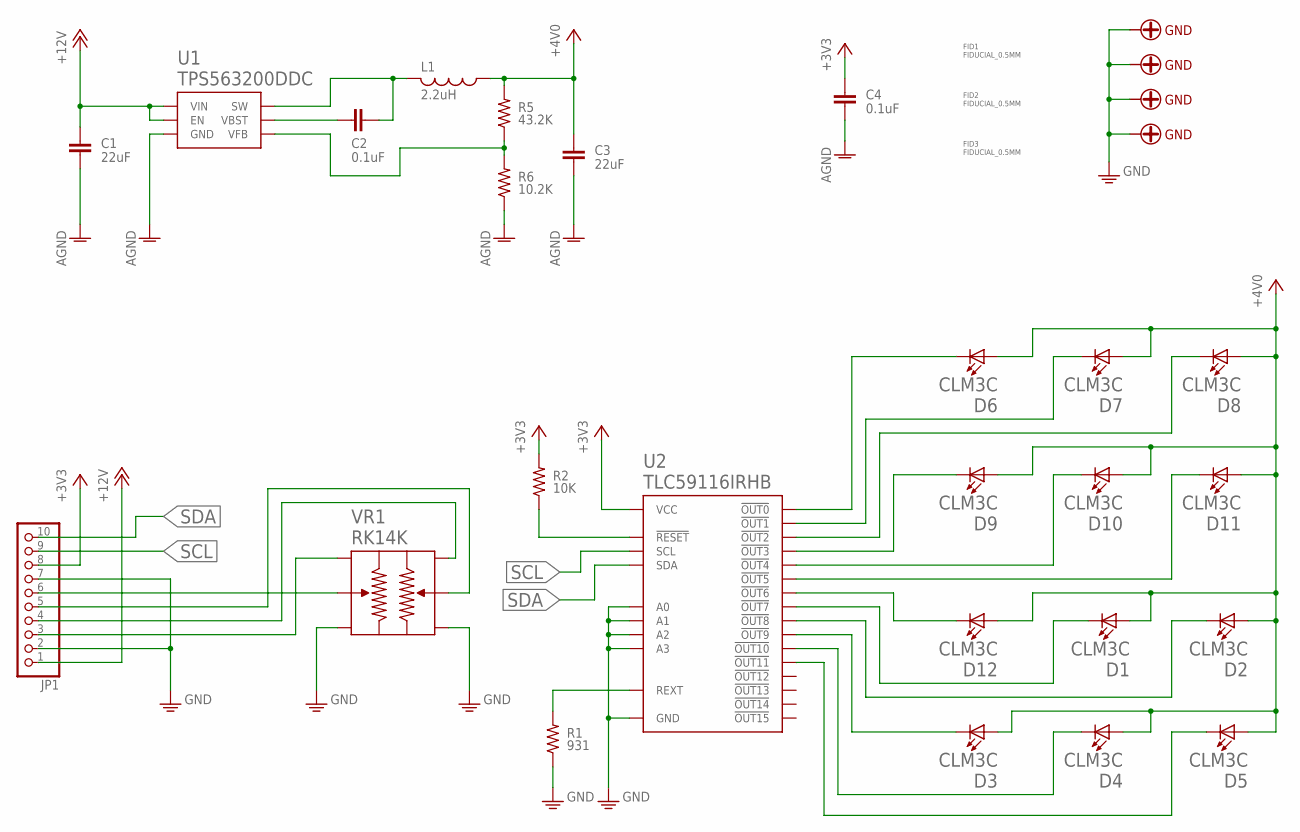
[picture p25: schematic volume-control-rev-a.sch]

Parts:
AGND: SCREW-THRU-GND-#4
C1, C3: 22uF; C1210
C2: 0.1uF; C0603
C4: 0.1uF; C0402
D1, D2, D3, D4, D5, D6, D7, D8, D9, D10, D11, D12: CLM3C; PLCC-2; MPN CLM3C-WKW-CXAYA453
FID1, FID2, FID3: FIDUCIAL_0.5MM
JP1: PINHD-1X10; 1X10; MPN 22-05-3101
L1: 2.2uH; COILCRAFT-XFL4020; MPN XFL4020-222MEB
R1: 931; R0402
R2: 10K; R0402
R5: 43.2K; R0402
R6: 10.2K; R0402
U1: TPS563200DDC; R-PDSO-G6-DBV; MPN TPS563200DDCT
U2: TLC59116IRHB; S-PVQFN-N32-RHB; MPN TLC59116IRHB
U$2, U$3, U$4: SCREW-THRU-GND-#4
VR1: RK14K

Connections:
+3V3: C4.1, JP1.8, R2.2, U2.P$27 (VCC)
+4V0: C3.1, D1.ANODE (A), D2.ANODE (A), D3.ANODE (A), D4.ANODE (A), D5.ANODE (A), D6.ANODE (A), D7.ANODE (A), D8.ANODE (A), D9.ANODE (A), D10.ANODE (A), D11.ANODE (A), D12.ANODE (A), L1.P$1 (1), R5.2
+12V: C1.1, JP1.1, U1.3 (VIN), U1.5 (EN)
AGND: C1.2, C3.2, C4.2, R6.1, U1.1 (GND)
GND: AGND.P$1, AGND.P$2, AGND.P$3, AGND.P$4, AGND.P$5, AGND.P$6, AGND.P$7, AGND.P$8, AGND.P$9, JP1.2, JP1.7, R1.1, U2.P$1 (A2), U2.P$2 (A3), U2.P$7 (GND), U2.P$18 (GND), U2.P$23 (GND), U2.P$31 (A0), U2.P$32 (A1), U2.P$EP (GND), U2.P$EP1 (GND), U2.P$EP2 (GND), U2.P$EP3 (GND), U2.P$EP4 (GND), U2.P$EP5 (GND), U$2.P$1, U$2.P$2, U$2.P$3, U$2.P$4, U$2.P$5, U$2.P$6, U$2.P$7, U$2.P$8, U$2.P$9, U$3.P$1, U$3.P$2, U$3.P$3, U$3.P$4, U$3.P$5, U$3.P$6, U$3.P$7, U$3.P$8, U$3.P$9, U$4.P$1, U$4.P$2, U$4.P$3, U$4.P$4, U$4.P$5, U$4.P$6, U$4.P$7, U$4.P$8, U$4.P$9, VR1.L3 (OUT_L), VR1.R3 (OUT_R)
LEFT_IN: JP1.3, VR1.L1 (IN_L)
LEFT_OUT: JP1.6, VR1.L2 (WIPER_L)
unnamed: D6.CATHODE (C), U2.P$3 (!OUT0)
unnamed: D7.CATHODE (C), U2.P$4 (!OUT1)
unnamed: D8.CATHODE (C), U2.P$5 (!OUT2)
unnamed: D3.CATHODE (C), U2.P$15 (!OUT9)
unnamed: D4.CATHODE (C), U2.P$16 (!OUT10)
unnamed: D5.CATHODE (C), U2.P$17 (!OUT11)
unnamed: D9.CATHODE (C), U2.P$6 (!OUT3)
unnamed: D10.CATHODE (C), U2.P$8 (!OUT4)
unnamed: D11.CATHODE (C), U2.P$9 (!OUT5)
unnamed: D12.CATHODE (C), U2.P$10 (!OUT6)
unnamed: D1.CATHODE (C), U2.P$11 (!OUT7)
unnamed: D2.CATHODE (C), U2.P$14 (!OUT8)
unnamed: C2.2, L1.P$2 (2), U1.2 (SW)
unnamed: C2.1, U1.6 (VBST)
unnamed: R5.1, R6.2, U1.4 (VFB)
unnamed: R2.1, U2.P$24 (!RESET)
unnamed: R1.2, U2.P$30 (REXT)
RIGHT_IN: JP1.4, VR1.R1 (IN_R)
RIGHT_OUT: JP1.5, VR1.R2 (WIPER_R)
SCL: JP1.9, U2.P$25 (SCL)
SDA: JP1.10, U2.P$26 (SDA)

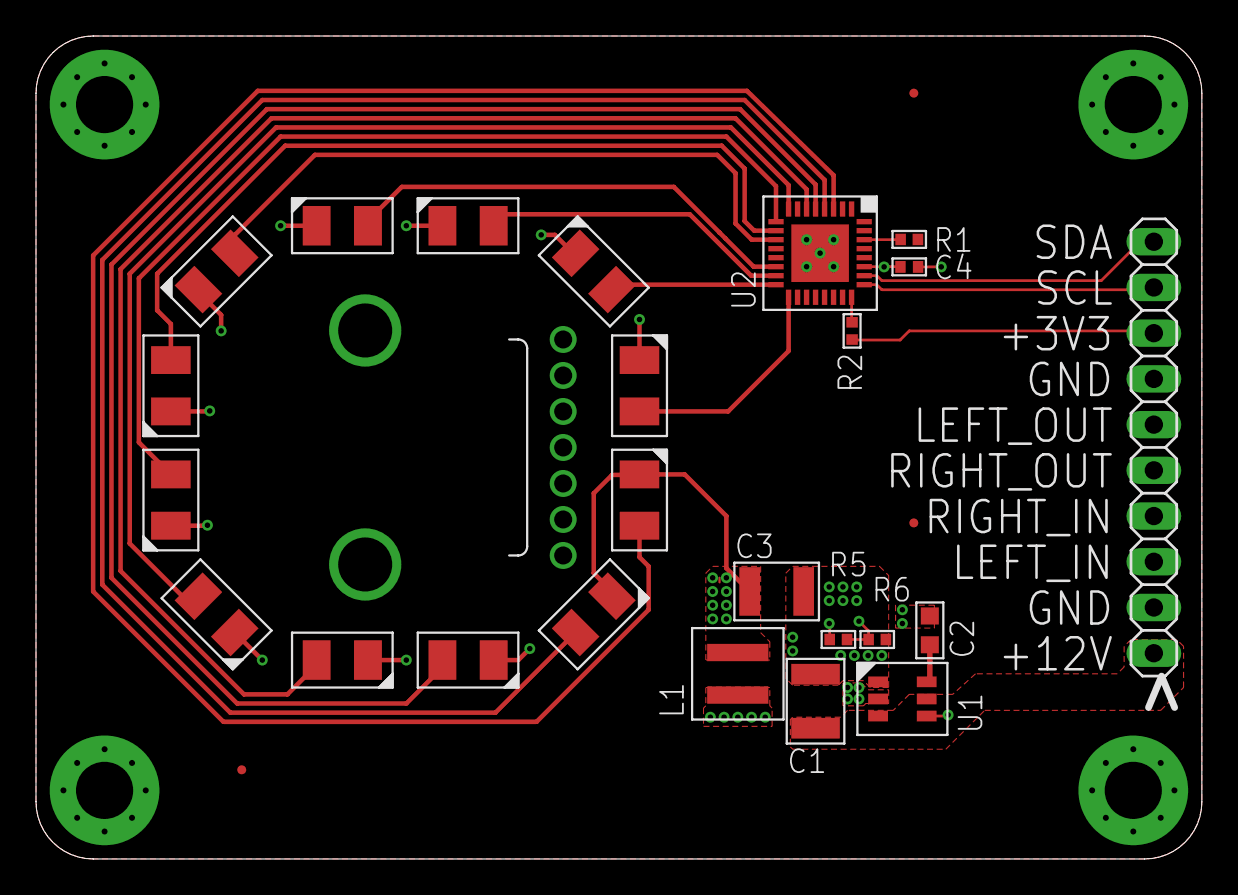
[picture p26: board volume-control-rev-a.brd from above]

Board: 4 copper layers, 64.8 x 45.7 mm, 33 parts (1 on the bottom side), 28 nets.

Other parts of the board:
U$1: NF_LOGO

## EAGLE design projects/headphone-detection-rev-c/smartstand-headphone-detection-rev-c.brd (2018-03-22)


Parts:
C3: 100nF; C0402
C5, C6: 10uF; C0603
C7: 4.7uF; C0603
J1: T1M-5POS; T1M-SINGLE-5POS
R1: 47K; R0402
R3, R4, R5, R6: 10K; R0402
TP1, TP2: TESTPOINT-WITH-GND; TESTPOINT-1.5-WITH-GND
U1: VL6180XV0NR; VL6180X
U2: LP5907MFX-2.8; R-PDSO-G5-DBV
U3, U4: BSS138; SOT23
U$1, U$2, U$3: FIDUCIAL-1MM; FIDUCIAL_1MM

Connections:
+2V8: C3.1, C6.1, C7.1, R1.2, R3.2, R4.2, TP2.S, U1.8 (AVDD_VCSEL), U1.10 (AVDD), U2.5 (OUT), U3.1 (G), U4.1 (G)
+3V3: C5.1, J1.2, R5.2, R6.2, TP1.S, U2.1 (IN), U2.3 (EN)
AGND: C3.2, C5.2, C6.2, C7.2, J1.1, J1.5, TP1.G, TP2.G, U1.9 (AVSS_VCSEL), U1.12 (AVSS), U2.2 (GND)
LOCAL_SCL: R4.1, U1.5 (SCL), U3.2 (S)
LOCAL_SDA: R3.1, U1.6 (SDA), U4.2 (S)
unnamed: R1.1, U1.4 (GPIO0)
SCL: J1.4, R5.1, U3.3 (D)
SDA: J1.3, R6.1, U4.3 (D)


Board: 2 copper layers, 25.4 x 25.4 mm, 19 parts (0 on the bottom side), 8 nets.

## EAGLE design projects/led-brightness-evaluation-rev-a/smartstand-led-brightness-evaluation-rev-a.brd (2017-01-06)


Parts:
D1, D2, D3, D4, D5, D6: CLM3C; PLCC-2
JP1: PINHD-1X2; 1X02
R1, R2, R3, R4, R5, R6: 100; R0805
U$1, U$2: FIDUCIAL-1MM; FIDUCIAL_1MM

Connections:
+5V: D1.ANODE (A), D2.ANODE (A), D3.ANODE (A), D4.ANODE (A), D5.ANODE (A), D6.ANODE (A), JP1.2
AGND: JP1.1, R1.2, R2.2, R3.2, R4.2, R5.2, R6.2
unnamed: D1.CATHODE (C), R1.1
unnamed: D2.CATHODE (C), R2.1
unnamed: D3.CATHODE (C), R3.1
unnamed: D4.CATHODE (C), R4.1
unnamed: D5.CATHODE (C), R5.1
unnamed: D6.CATHODE (C), R6.1


Board: 2 copper layers, 50.8 x 36.8 mm, 15 parts (0 on the bottom side), 8 nets.

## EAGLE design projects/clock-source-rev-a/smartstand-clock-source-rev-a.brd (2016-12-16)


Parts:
C1: 100nF; C0402
C2: 1uF; C0603
J1: RECE-20279-001E-01; IPEX-MHF
JP1: PINHD-1X5; 1X05
X1: KC2520K; KC2520C

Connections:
+3V3: C1.1, C2.1, JP1.1, JP1.5, X1.P$1 (!EN), X1.P$4 (VDD)
AGND: C1.2, C2.2, J1.P$1 (GND), J1.P$2 (GND), JP1.2, JP1.4, X1.P$2 (GND)
CLK_SRC: JP1.3
unnamed: J1.P$3 (IN), X1.P$3 (CLK)


Board: 2 copper layers, 25.1 x 26.9 mm, 5 parts (0 on the bottom side), 3 nets.

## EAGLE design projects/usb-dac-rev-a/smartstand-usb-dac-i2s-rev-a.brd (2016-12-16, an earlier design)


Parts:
C2: 1uF; C0603
C3, C5: 10uF; C0603
C4: 4.7uF; C0603
C6, C9, C11: 10nF; C0402
C7, C10, C12, C13, C14, C15, C16, C17, C18, C19, C20, C21, C22, C23, C28, C30: 100nF; C0402
R4, R5: 10K; R0402
U3: LP5912-3.3; P-PWSON-N6
U4: LP3879MR-1.0; PSOP-8-POWERPAD-DDA
U5: TPS3702; R-PDSO-G6

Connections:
3V3_PG: R4.1, U3.P$3 (PG), U4.8 (EN); also elsewhere on the board
!RESET: R5.1, U5.1 (!UV), U5.6 (!OV); also elsewhere on the board
+1V0: C5.1, C7.1, C11.2, C14.1, C15.1, C16.1, C17.1, C18.1, C19.1, C20.1, C21.1, C22.1, C23.1, U4.5 (OUT), U4.6 (SENSE), U5.3 (SENSE); also elsewhere on the board
+3V3: C3.1, C10.1, C12.1, C13.1, C28.1, C30.1, R4.2, R5.2, U3.P$1 (OUT); also elsewhere on the board
+5V: C2.2, C4.2, C9.2, U3.P$4 (EN), U3.P$6 (IN), U4.4 (IN), U5.4 (SET), U5.5 (VDD); also elsewhere on the board
AGND: C2.1, C3.2, C4.1, C5.2, C6.1, C7.2, C9.1, C10.2, C11.1, C12.2, C13.2, C14.2, C15.2, C16.2, C17.2, C18.2, C19.2, C20.2, C21.2, C22.2, C23.2, C28.2, C30.2, U3.P$5 (GND), U3.P$8 (GND), U3.P$9 (GND), U3.P$EP (GND), U4.3 (GND), U4.EP (GND), U4.P$1 (GND), U4.P$2 (GND), U4.P$3 (GND), U4.P$4 (GND), U4.P$5 (GND), U4.P$6 (GND), U5.2 (GND); also elsewhere on the board
unnamed: C6.2, U4.1 (BYPASS)


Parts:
C1, C8: 100nF; C0402
R2, R3: 33; R0402
R6: 4.7; R0402
R7: 1K; R0402
U2: XUF208-256-TQ64; TQFP-64-EXPOSED-PAD
X1: 24MHz; KC2520C

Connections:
!RESET: U2.P$57 (!RST); also elsewhere on the board
+1V0: R6.2, U2.P$9 (VDD), U2.P$10 (VDD), U2.P$20 (VDD), U2.P$27 (USB_VDD), U2.P$31 (VDD), U2.P$39 (VDD), U2.P$40 (VDD), U2.P$41 (VDD), U2.P$52 (VDD), U2.P$56 (VDD), U2.P$59 (VDD); also elsewhere on the board
+3V3: C1.2, R7.2, U2.P$3 (VDDIOL), U2.P$13 (VDDIOL), U2.P$22 (USB_VDD33), U2.P$34 (VDDIOR), U2.P$44 (VDDIOR), U2.P$55 (OTP_VCC), X1.P$1 (!EN), X1.P$4 (VDD); also elsewhere on the board
AGND: C1.1, C8.2, U2.P$54 (PLL_AGND), U2.P$65 (GND), U2.P$66 (GND), U2.P$67 (GND), U2.P$68 (GND), U2.P$69 (GND), U2.P$70 (GND), U2.P$71 (GND), U2.P$72 (GND), U2.P$73 (GND), U2.P$74 (GND), X1.P$2 (GND); also elsewhere on the board
AUDIO_STATUS: U2.P$16 (X0D11); also elsewhere on the board
CLK: U2.P$58 (CLK), X1.P$3 (CLK); also elsewhere on the board
I2S_BCLK: U2.P$2 (X0D38); also elsewhere on the board
I2S_DATA: U2.P$4 (X0D39); also elsewhere on the board
I2S_LRCLK: U2.P$1 (X0D36); also elsewhere on the board
I2S_MCLK: U2.P$64 (X0D37); also elsewhere on the board
LINK_DOWN0: U2.P$6 (X0D41); also elsewhere on the board
LINK_DOWN1: U2.P$5 (X0D40); also elsewhere on the board
LINK_UP0: R3.2; also elsewhere on the board
LINK_UP1: R2.2; also elsewhere on the board
MCLK_SEL: U2.P$42 (X0D35); also elsewhere on the board
unnamed: C8.1, R6.1, U2.P$53 (PLL_AVDD)
unnamed: R3.1, U2.P$7 (X0D42)
unnamed: R2.1, U2.P$8 (X0D43)
unnamed: R7.1, U2.P$11 (X0D01)


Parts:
C24: 2.2uF; C0603
J1: DX4R005H91R1500
J2, J5: PINHD-1X5; 1X05
J3: RECE-20279-001E-01; IPEX-MHF
J4: PINHD-2X10; 2X10
R1: 43.2; R0402
U1: USBUF01W6; SOT323-6L
U2: XUF208-256-TQ64; TQFP-64-EXPOSED-PAD

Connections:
!RESET: J4.15; also elsewhere on the board
+3V3: J5.1, J5.5; also elsewhere on the board
+5V: C24.1, J1.P$1 (VBUS), U1.P$5 (VCC), U2.P$23 (USB_VBUS); also elsewhere on the board
AGND: C24.2, J1.P$5 (GND), J2.1, J2.5, J3.P$1 (GND), J3.P$2 (GND), J4.4, J4.8, J4.12, J4.16, J4.20, J5.2, J5.4, R1.1, U1.P$2 (GND); also elsewhere on the board
CLEAN_USB_D_N: U1.P$3 (D2), U2.P$26 (USB_D-)
CLEAN_USB_D_P: U1.P$1 (D1), U2.P$25 (USB_D+)
I2S_BCLK: J2.3; also elsewhere on the board
I2S_DATA: J2.2; also elsewhere on the board
I2S_LRCLK: J2.4; also elsewhere on the board
I2S_MCLK: J3.P$3 (IN); also elsewhere on the board
LINK_DOWN0: J4.14; also elsewhere on the board
LINK_DOWN1: J4.18; also elsewhere on the board
LINK_UP0: J4.10; also elsewhere on the board
LINK_UP1: J4.6; also elsewhere on the board
MCLK_SEL: J5.3; also elsewhere on the board
unnamed: R1.2, U2.P$24 (USB_RTUNE)
unnamed: J4.7, U2.P$60 (TMS)
unnamed: J4.9, U2.P$61 (TCK)
unnamed: J4.5, U2.P$62 (TDI)
unnamed: J4.13, U2.P$63 (TDO)
RAW_USB_D_N: J1.P$2 (D-), U1.P$4 (D3)
RAW_USB_D_P: J1.P$3 (D+), U1.P$6 (D4)


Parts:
D1, D2, D3: 1.8V, 10mA; DIALIGHT-0603
R8: 330; R0402
R9, R10: 150; R0402
TP1, TP2, TP3, TP5, TP6: TESTPOINT-1.5MM; TESTPOINT-1.5
TP4: PINHD-1X1; 1X01
U6: SN74LVC1G32DRL; R-PDSO-N5

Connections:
3V3_PG: TP5.P$1; also elsewhere on the board
+1V0: TP3.P$1; also elsewhere on the board
+3V3: D2.1 (A), TP2.P$1, U6.5 (VDD); also elsewhere on the board
+5V: D1.1 (A), TP1.P$1; also elsewhere on the board
AGND: R8.1, R9.1, R10.1, TP4.1, U6.3 (GND); also elsewhere on the board
AUDIO_STATUS: U6.1 (A), U6.2 (B); also elsewhere on the board
CLK: TP6.P$1; also elsewhere on the board
unnamed: D1.2 (C), R8.2
unnamed: D2.2 (C), R9.2
unnamed: D3.1 (A), U6.4 (Q)
unnamed: D3.2 (C), R10.2


Board: 4 copper layers, 49.3 x 37.8 mm, 57 parts (0 on the bottom side), 35 nets.

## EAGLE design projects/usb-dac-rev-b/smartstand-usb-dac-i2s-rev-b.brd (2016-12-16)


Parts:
C2: 1uF; C0603
C3, C5: 10uF; C0603
C4: 4.7uF; C0603
C6, C9, C11: 10nF; C0402
C7, C10, C12, C13, C14, C15, C16, C17, C18, C19, C20, C21, C22, C23, C28, C30: 100nF; C0402
R4, R5: 10K; R0402
U3: LP5912-3.3; P-PWSON-N6
U4: LP3879MR-1.0; PSOP-8-POWERPAD-DDA
U5: TPS3702; R-PDSO-G6

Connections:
3V3_PG: R4.1, U3.P$3 (PG), U4.8 (EN)
!RESET: R5.1, U5.1 (!UV), U5.6 (!OV); also elsewhere on the board
+1V0: C5.1, C7.1, C11.2, C14.1, C15.1, C16.1, C17.1, C18.1, C19.1, C20.1, C21.1, C22.1, C23.1, U4.5 (OUT), U4.6 (SENSE), U5.3 (SENSE); also elsewhere on the board
+3V3: C3.1, C10.1, C12.1, C13.1, C28.1, C30.1, R4.2, R5.2, U3.P$1 (OUT); also elsewhere on the board
+5V: C2.2, C4.2, C9.2, U3.P$4 (EN), U3.P$6 (IN), U4.4 (IN), U5.4 (SET), U5.5 (VDD); also elsewhere on the board
AGND: C2.1, C3.2, C4.1, C5.2, C6.1, C7.2, C9.1, C10.2, C11.1, C12.2, C13.2, C14.2, C15.2, C16.2, C17.2, C18.2, C19.2, C20.2, C21.2, C22.2, C23.2, C28.2, C30.2, U3.P$5 (GND), U3.P$8 (GND), U3.P$9 (GND), U3.P$EP (GND), U4.3 (GND), U4.EP (GND), U4.P$1 (GND), U4.P$2 (GND), U4.P$3 (GND), U4.P$4 (GND), U4.P$5 (GND), U4.P$6 (GND), U5.2 (GND); also elsewhere on the board
unnamed: C6.2, U4.1 (BYPASS)


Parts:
C1, C8: 100nF; C0402
R2, R3: 33; R0402
R6: 4.7; R0402
R7: 1K; R0402
R13, R14: 4.7K; R0402
U2: XUF208-256-TQ64; TQFP-64-EXPOSED-PAD
X1: 24MHz; KC2520C

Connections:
!RESET: U2.P$57 (!RST); also elsewhere on the board
+1V0: R6.2, U2.P$9 (VDD), U2.P$10 (VDD), U2.P$20 (VDD), U2.P$27 (USB_VDD), U2.P$31 (VDD), U2.P$39 (VDD), U2.P$40 (VDD), U2.P$41 (VDD), U2.P$52 (VDD), U2.P$56 (VDD), U2.P$59 (VDD); also elsewhere on the board
+3V3: C1.2, R7.2, R13.2, R14.2, U2.P$3 (VDDIOL), U2.P$13 (VDDIOL), U2.P$22 (USB_VDD33), U2.P$34 (VDDIOR), U2.P$44 (VDDIOR), U2.P$55 (OTP_VCC), X1.P$1 (!EN), X1.P$4 (VDD); also elsewhere on the board
AGND: C1.1, C8.2, U2.P$54 (PLL_AGND), U2.P$65 (GND), U2.P$66 (GND), U2.P$67 (GND), U2.P$68 (GND), U2.P$69 (GND), U2.P$70 (GND), U2.P$71 (GND), U2.P$72 (GND), U2.P$73 (GND), U2.P$74 (GND), X1.P$2 (GND); also elsewhere on the board
AUDIO_ENABLE: U2.P$19 (X0D07); also elsewhere on the board
AUDIO_STREAMING: U2.P$17 (X0D05); also elsewhere on the board
CLK: U2.P$58 (CLK), X1.P$3 (CLK); also elsewhere on the board
I2C_SCL: R13.1, U2.P$14 (X0D00); also elsewhere on the board
I2C_SDA: R14.1, U2.P$16 (X0D11); also elsewhere on the board
I2S_BCLK: U2.P$2 (X0D38); also elsewhere on the board
I2S_DATA: U2.P$4 (X0D39); also elsewhere on the board
I2S_LRCLK: U2.P$1 (X0D36); also elsewhere on the board
I2S_MCLK: U2.P$64 (X0D37); also elsewhere on the board
LINE_OUT_SEL: U2.P$18 (X0D06); also elsewhere on the board
LINK_DOWN0: U2.P$6 (X0D41); also elsewhere on the board
LINK_DOWN1: U2.P$5 (X0D40); also elsewhere on the board
LINK_UP0: R3.2; also elsewhere on the board
LINK_UP1: R2.2; also elsewhere on the board
MCLK_SEL: U2.P$42 (X0D35); also elsewhere on the board
unnamed: R3.1, U2.P$7 (X0D42)
unnamed: R2.1, U2.P$8 (X0D43)
unnamed: R7.1, U2.P$11 (X0D01)
PLL_AVDD: C8.1, R6.1, U2.P$53 (PLL_AVDD); also elsewhere on the board
USB_CONNECTED: U2.P$15 (X0D04); also elsewhere on the board
VOLUME_A: U2.P$47 (X0D28); also elsewhere on the board
VOLUME_B: U2.P$49 (X0D29); also elsewhere on the board
VOLUME_C: U2.P$50 (X0D30); also elsewhere on the board


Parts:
C24: 2.2uF; C0603
J1: DX4R005H91R1500
J3: PINHD-2X3; 2X03
J4: PINHD-1X4; 1X04
J5: PINHD-1X7; 1X07
J6: PINHD-1X5; 1X05
J7: RECE-20279-001E-01; IPEX-MHF
R1: 43.2; R0402
U1: TPD4E02B04; R-PUSON-N10
U2: XUF208-256-TQ64; TQFP-64-EXPOSED-PAD

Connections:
+3V3: J6.1, J6.5; also elsewhere on the board
+5V: C24.1, J1.P$1 (VBUS), J5.1, U1.P$1 (IO1), U1.P$10 (IO1), U2.P$23 (USB_VBUS); also elsewhere on the board
AGND: C24.2, J1.P$5 (GND), J3.2, J3.4, J3.6, J4.2, J4.4, J5.7, J6.2, J6.4, J7.P$1 (GND), J7.P$2 (GND), R1.1, U1.P$3 (GND), U1.P$8 (GND); also elsewhere on the board
AUDIO_ENABLE: J5.6; also elsewhere on the board
I2C_SCL: J4.1; also elsewhere on the board
I2C_SDA: J4.3; also elsewhere on the board
I2S_BCLK: J3.3; also elsewhere on the board
I2S_DATA: J3.1; also elsewhere on the board
I2S_LRCLK: J3.5; also elsewhere on the board
I2S_MCLK: J7.P$3 (IN); also elsewhere on the board
LINE_OUT_SEL: J5.5; also elsewhere on the board
MCLK_SEL: J6.3; also elsewhere on the board
unnamed: R1.2, U2.P$24 (USB_RTUNE)
USB_D_N: J1.P$2 (D-), U1.P$2 (IO2), U1.P$9 (IO2), U2.P$26 (USB_D-)
USB_D_P: J1.P$3 (D+), U1.P$4 (IO3), U1.P$7 (IO3), U2.P$25 (USB_D+)
VOLUME_A: J5.4; also elsewhere on the board
VOLUME_B: J5.3; also elsewhere on the board
VOLUME_C: J5.2; also elsewhere on the board

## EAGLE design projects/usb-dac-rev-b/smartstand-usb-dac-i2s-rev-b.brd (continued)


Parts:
D1, D2, D3, D4, D5: 1.8V, 10mA; DIALIGHT-0603
R8: 330; R0402
R9, R10, R11, R12: 150; R0402
U6: SN74LVC3G34; R-PDSO-G8

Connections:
+3V3: D2.1 (A), U6.8 (VDD); also elsewhere on the board
+5V: D1.1 (A); also elsewhere on the board
AGND: R8.1, R9.1, R10.1, R11.1, R12.1, U6.4 (GND); also elsewhere on the board
AUDIO_STREAMING: U6.3 (A); also elsewhere on the board
LINE_OUT_SEL: U6.6 (A); also elsewhere on the board
unnamed: D4.1 (A), U6.5 (Y)
unnamed: D1.2 (C), R8.2
unnamed: D2.2 (C), R9.2
unnamed: D3.1 (A), U6.7 (Y)
unnamed: D3.2 (C), R10.2
unnamed: D4.2 (C), R11.2
unnamed: D5.1 (A), U6.2 (Y)
unnamed: D5.2 (C), R12.2
USB_CONNECTED: U6.1 (A); also elsewhere on the board


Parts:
J2: PINHD-2X10; 2X10
TP1, TP2, TP3, TP6, TP11: TESTPOINT-1.5MM; TESTPOINT-1.5
TP4, TP7, TP8, TP10, TP12: TESTPOINT-1.5MM-SQUARE; TESTPOINT-1.5-SQUARE
U2: XUF208-256-TQ64; TQFP-64-EXPOSED-PAD

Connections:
!RESET: J2.15; also elsewhere on the board
+1V0: TP3.P$1; also elsewhere on the board
+3V3: TP2.P$1; also elsewhere on the board
+5V: TP1.P$1; also elsewhere on the board
AGND: J2.4, J2.8, J2.12, J2.16, J2.20, TP4.P$1, TP7.P$1, TP8.P$1, TP10.P$1, TP12.P$1; also elsewhere on the board
CLK: TP6.P$1; also elsewhere on the board
LINK_DOWN0: J2.14; also elsewhere on the board
LINK_DOWN1: J2.18; also elsewhere on the board
LINK_UP0: J2.10; also elsewhere on the board
LINK_UP1: J2.6; also elsewhere on the board
unnamed: J2.7, U2.P$60 (TMS)
unnamed: J2.9, U2.P$61 (TCK)
unnamed: J2.5, U2.P$62 (TDI)
unnamed: J2.13, U2.P$63 (TDO)
PLL_AVDD: TP11.P$1; also elsewhere on the board


Board: 4 copper layers, 62.9 x 51.7 mm, 69 parts (0 on the bottom side), 45 nets.

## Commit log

2016-12-16 Initial import.
    This includes all design files as they currently stand, so we won't have
    much history at all, only just tweaks to the final design.
    We have DRC rules and datasheets for many of the major components.
    [smartstand-amplifier-rev-a.sch, smartstand-clock-source-rev-a.brd, smartstand-clock-source-rev-a.csv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]
2016-12-17 Ensure all resistors and capacitors in audio path are spec'd correctly.
    Basically just went through and made sure we had 0.1% tolerance on the
    resistors, with the exception of 1% on the outout resistors because
    percision ones (aka current sense resistors ) are $xx.xx, and made sure
    that our capacitors are C0G/NP0. I switched to film capacitors for the
    DC blocking input capacitors on the output stage because values that
    large for C0G/NP0 ceramics don't exist on Mouser.
    Also added ESD protection to the headphone output and line output,
    specifically using the TPD2E007, which is specified for AC signals like
    ours, and won't activate with our -/+10V rails.
    [smartstand-usb-dac-amplifier-rev-a.brd, smartstand-usb-dac-amplifier-rev-a.sch]
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2016-12-18 Adding more part numbers and fixing incorrect ones.
    [smartstand-usb-dac-amplifier-rev-a.brd, smartstand-usb-dac-amplifier-rev-a.sch]
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2016-12-20 Fix PJ-002A footprint and remove cream from testpoints.
    [smartstand-usb-dac-amplifier-rev-a.brd, smartstand-usb-dac-amplifier-rev-a.sch]
2016-12-21 Some housekeeping tasks to keep up the schematic.
    Switched from R_US/R_US-VERTICAL to RESISTOR and RESISTOR-HORIZONTAL,
    which brings up in line with our usage of CAPACITOR and
    CAPACITOR-HORIZONTAL. Ultimately, our likelihood of using through-hole
    passives is very, very low, so I'm trying to commit to pruning down our
    rcl (to eventually be named 'passives') library to the most basic/common
    SMD passives footprints and nothing more
    Also added part numbers, en masse, for many passives. This is taking
    advantage of our new tooling for finding inconsistencies in the
    schematic, such as parts missing a part number or identical parts
    (device and value) with different part numbers attached to them.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
    [smartstand-usb-dac-amplifier-rev-a.brd, smartstand-usb-dac-amplifier-rev-a.sch]
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2016-12-23 Alright, tests catch failures properly so going back to clean.
    [smartstand-usb-dac-amplifier-rev-a.brd, smartstand-usb-dac-amplifier-rev-a.sch]
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2016-12-23 Fixed up the NRJ6HH footprint which let us push it further out.
    [smartstand-usb-dac-amplifier-rev-a.brd, smartstand-usb-dac-amplifier-rev-a.sch]
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2016-12-24 Fix some part number issues.
    [smartstand-usb-dac-amplifier-rev-a.brd, smartstand-usb-dac-amplifier-rev-a.sch]
2016-12-26 Minor board layout tweaks.
    Adjusted how we route the USB signals to better take advantage of the
    type B connector, which now lets us avoid a layer transition. We're
    about 37mils difference between the pair lengths which is well within
    bounds of the 100ps skew allowed by the USB specification.
    Also, I mistakenly forgot to route power into the pigtail between the
    main board and the headphone detection daughterboard, which is now
    rectified. We're sending it DVDD (3V3) so that it needs no regulator of
    its own. We'll need to make sure that we do have a lot of bulk
    capacitance since the pigtail will be 8-12 inches long, and the
    measurement current can be large, and thus high di/dt, with freque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
    [smartstand-usb-dac-amplifier-rev-a.brd, smartstand-usb-dac-amplifier-rev-a.sch]
2016-12-26 Adjust the I2C pinout on the daughterboard connector.
    This will let us have cleaner routing on the small daughterboard which
    houses the proximity sensor.
    [smartstand-usb-dac-amplifier-rev-a.brd, smartstand-usb-dac-amplifier-rev-a.sch]
2016-12-26 Add the rev A of the headphone detection daughterboard.
    This board houses the VCNL4010 proximity sensor which will be embedded
    in the stand arm to detect when the headphones are present/sitting on
    the arm.
    We'll speak to it via I2C in a simple polling fashion to determine the
    state of docking.
    [headphone-detection-rev-a.brd, headphone-detection-rev-a.sch]
2016-12-27 Big updates to the headphone detection daughterboard.
    In no particular order:
    - we're now using the VL6180X (micro LIDAR, basically)
    - which needs 2V8 so we have an on-board regulator
    - which means we need to interface with 3V3 I2C logic so we
    - added level translation FETs for each I2C line
    - added test points for the two supply rails
    [headphone-detection-rev-a.brd, headphone-detection-rev-a.sch]
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2016-12-27 Add fiducials and fix ERC/DRC errors.
    [smartstand-usb-dac-amplifier-rev-a.brd, smartstand-usb-dac-amplifier-rev-a.sch]
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2017-01-03 Switch everything to vector fonts and add LEDs for knob illumination.
    We added LEDs around the volume control potentiometer so that we could
    get an underlighting effect on the volume knob. The base now has
    corresponding holes inside the support structure/cavity that the volume
    knob sits around, and since we engineered it so that the knob has a
    small gap from the base, the new holes added will allow light to escape
    all the way out, and under the volume knob, providing a soft white glow
    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
    [smartstand-usb-dac-amplifier-rev-a.brd, smartstand-usb-dac-amplifier-rev-a.sch]
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2017-01-06 Create LED evaluation board for volume knob lighting.
    We're just making a simple board here that emulates the layout of the
    LEDs on the main board, so we can see how hot things get and how much
    actual light there is, since we want enough to "escape" as it goes
    through webbed-out passages inside the volume knob.
    [smartstand-led-brightness-evaluation-rev-a.brd, smartstand-led-brightness-evaluation-rev-a.sch]
2017-01-06 DFM tweaks to the headphone detection daughterboard.
    Switched to vector fonts to better repicate what will end up on our
    actual boards, and tweaked net label sizes.
    Also switched one capacitor to a different package/PN for cost reasons.
    [smartstand-headphone-detection-rev-a.brd, smartstand-headphone-detection-rev-a.sch]
2017-01-19 Created a rev B of the headphone detection board.
    Some simple changes:
    - added a third fiducial to allow better alignment
    - adjusted placement/routing of regulator to account for fiducial
    - updated footprint of VL6180X to include pin 1 indicator
    - updated board info to indicate rev B
    [smartstand-headphone-detection-rev-b.brd, smartstand-headphone-detection-rev-b.sch]
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2017-02-09 Pull enclosure files into the repository.
    Initially, I had the enclosure files in a separate repository. As I get
    closer to "cutting" a final revision of the board, though, it makes more
    sense to bundle it all in one so that I can tag the commit that
    represents the finalized board *and* enclosure, ensuring proper fit,
    etc.
    [2920L_0_6A.sldprt, 91375A730_ALLOY STEEL CUP POINT SET SCREW.SLDPRT, 92525A198_THREAD-FORMING SCREW FOR SHEET METAL IRON.SLDPRT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]
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2017-02-23 Clean up some wiring; better clearances and 'tightness'
    [smartstand-usb-dac-amplifier-rev-a.brd]
2017-02-23 Add mounting hole between USB jack and DC power jack.
    That area was a little flimsy and didn't have a mounting hole parallel
    to the edge, leaving too much of an overhang for my tastes.
    Luckily, we had just enough space between the connectors to fit in a
    mounting hole, and so, voila!
    [smartstand-usb-dac-amplifier-rev-a.brd]
2017-02-23 Adjust power jack footprint and placement.
    After getting the test boards back, the PTH fitment is super loose, and
    because of that, it's hard to tell if things are positioned correctly.
    I went and back took real measurements of the pins, cross-referenced
    with what the datasheet says, and ran the numbers again using the IPC
    specification for the tightest fit.
    I also adjusted the footprint to better account for the centerline of
    the part. Now that the origin of the part is better situated, I
    positioned it such that it should yield the optimal board extension of
    1mm, letting it sit flush against the enclosure when installed.
    [smartstand-usb-dac-amplifier-rev-a.brd, smartstand-usb-dac-amplifier-rev-a.sch]
2017-02-23 Adjust RCA jack placement.
    After measuring with the test boards, we had about 1mm worth of distance
    from the front face of the RCA jacks to the edge of the board.
    Now the jack is shifted over to sit flush with the board edge, exposing
    that extra 1mm outside of the enclosure. This gets us to a more
    comfortable 6mm of exposed jack, for better plug seating.
    [smartstand-usb-dac-amplifier-rev-a.brd]
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2017-02-24 Incorporate the latest IDF changes into the model.
    This involves the nudging of connectors/ports on the board to maximize
    the engagement we can achieve.
    I also reworked some of the mates, and, I think, generally cleaned
    things up everrrrrr so slightly.
    I also regenerated the STL files after making said changes.
    [NRJ6HH.SLDPRT, pj-002a.SLDPRT, pjran2x1u_series.SLDPRT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]
2017-02-24 Tightening up fiducial to processor.
    [smartstand-usb-dac-amplifier-rev-a.brd]
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2017-09-12 Start working on rev B on the USB DAC/Amplifier board.
    I think I got far enough originally, even without building, to consider
    the design doable with the hardware and size constraints.
    Rev B will feature, primarily, a reduced average footprint: we'll split
    the actual audio processing and the volume control, which will let us
    avoid an oddly-shaped board. The board shape was inflating the pricing
    on board manufacture due to the overall high bounding box dimensions.
    Rev B will also, likely, include a slight tweak to the power stages --
    i.e. using through-hole electrolytics for increased capacity per
    board space unit and reduced component counter -- as well as better
    routing of the audio sign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
    [smartstand-usb-dac-amplifier-rev-b.brd, smartstand-usb-dac-amplifier-rev-b.sch]
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2017-09-13 First rough pass at the slimdown.
    I've roughly adjusted the dimensions and shoved everything in there.
    The routing isn't half bad, but it's gonna need a lot of tweaks, namely
    to get things in a better position, with better trace/space, with
    cleaner silkscreen layout.
    There's still some angles and airwires and obvious stuff to sort out
    but, otherwise, a good first pass.
    [smartstand-usb-dac-amplifier-rev-b.brd, smartstand-usb-dac-amplifier-rev-b.sch]
2017-09-14 More fixups and cleaup.
    Not too much changed here, but the airwires have been cleaned up.
    Still need to make sure that the connector offset from the edge is good,
    as well as go through each subsystem and redo functional/design checks.
    After that, I think I can properly clean up and tidy up the routing.
    [smartstand-usb-dac-amplifier-rev-b.brd, smartstand-usb-dac-amplifier-rev-b.sch]
2018-01-14 Torch the old enclosure design.
    Decided I really want something made out of wood, so we need to ditch
    the super curvy and abstract design some something simpler and more
    straight forward.
    [smartstand-base.SLDPRT, smartstand-base.STL, smartstand-base_plate.SLDPRT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]
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2018-03-31 Lots of updates and tweaks.
    This is the locked version for rev A of the volume control board.
    [smartstand-usb-dac-amplifier-rev-b.brd, smartstand-usb-dac-amplifier-rev-b.sch, volume-control-rev-a.brd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]
2018-09-07 Lots of cleanup.
    Fixing up some incorrect MPNs and package sizes for bulk capacitance, and cleaning up DRC bits. Also trying to move some bulk capacitance around the board to create a better supply plane.
    [smartstand-usb-dac-amplifier-rev-b.brd, smartstand-usb-dac-amplifier-rev-b.sch]
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2018-09-26 More BOM tweaking.
    We had some caps that were not sized properly for their expected voltages, so we've fixed that up, and we've added MPNs where necessary.
    [smartstand-usb-dac-amplifier-rev-b.brd, smartstand-usb-dac-amplifier-rev-b.sch]
2018-10-28 Cleaning up some of the power circuitry.
    A lot of generic cleanup here:
    - capacitor availability is painful, so reworking that
    - no need to use the smallest via possible when fewer bigger ones will do
    - use ranks to better allow flood pours to coexist
    [smartstand-usb-dac-amplifier-rev-b.brd, smartstand-usb-dac-amplifier-rev-b.sch]
